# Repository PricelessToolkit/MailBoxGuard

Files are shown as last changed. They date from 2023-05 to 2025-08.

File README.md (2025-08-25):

## ⚠️ MailBox Guard Production is Discontinued. The New version "[PirBOX-LITE](https://github.com/PricelessToolkit/PirBOX-LITE) or [PirBOX-MAX](https://github.com/PricelessToolkit/PirBOX-MAX)"

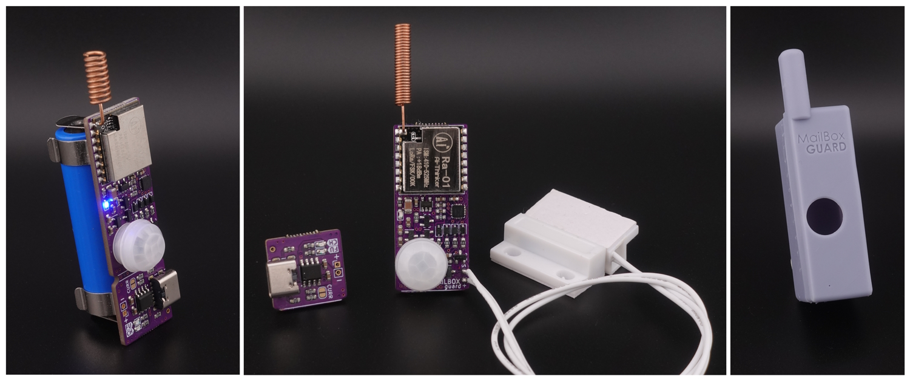
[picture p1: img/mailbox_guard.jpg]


🤗 Please consider subscribing to my [YouTube channel](https://www.youtube.com/@PricelessToolkit/videos)
Your subscription goes a long way in backing my work.



# Long Range "LoRa" Universal MailBox Sensor

### Can be integrated with Home Assistant, used via WhatsApp, or be operated offline.

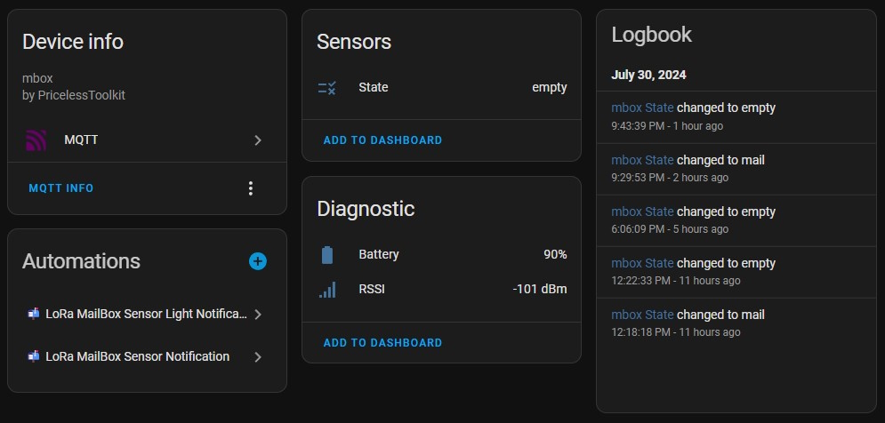
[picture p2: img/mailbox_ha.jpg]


### Use Cases

- Mailbox Sensor - "Code examples are provided"
- Alarm / Motion Sensor

### How it works - Mailbox Use Case

The Mailbox Guard is a device that detects when a new letter or package has been delivered to your mailbox using a PIR sensor and door reed switch. It can send a signal to your LoRa gateway, then the gateway sends a message via WiFi to `Home Assistant "MQTT" or its "API"` or to `WhatsApp` allowing you to receive notifications directly into your phone. Or you can use it offline, the gateway display will show the number of letters received, Battery status, and signal strength.

### Links

- YouTube video https://youtu.be/gf1WWKyEnbg
- My Shop

  - Mailbox Sensor [https://www.pricelesstoolkit.com/](https://www.pricelesstoolkit.com/en/projects/34-41-mailbox-guard-wireless-ir-sensor.html)
  - UNIProg Programmer [https://www.pricelesstoolkit.com/](https://www.pricelesstoolkit.com/en/projects/33-uniprog-uartupdi-programmer-33v.html)
  - Official Multiprotocol Gateway CapiBridge [https://www.pricelesstoolkit.com/](https://www.pricelesstoolkit.com/en/projects/42-129-capibridge-gateway-kit.html#/41-frequency-868_915_mhz)

- Gateway on Aliexpress [LILYGO® TTGO LoRa32 V2.1_1.6 Version 433/868/915Mhz](https://s.click.aliexpress.com/e/_DdCLj19)
- Pogo Pin Clamp [6 Pin Minimum 2.54mm pitch ](https://s.click.aliexpress.com/e/_Dm94yBf)
- Reed Switch "Normally open When the magnet is far away" "For soldering on PCB" https://s.click.aliexpress.com/e/_DkA1Sjp
- Reed Switch with cable "Normally open When the magnet is far away" https://s.click.aliexpress.com/e/_DFNJv1h
- Battery [Li-Ion 14500 800mA](https://s.click.aliexpress.com/e/_DDtU0iT)
- USB Battery charger "just in case" https://s.click.aliexpress.com/e/_DkDAztD

### Sensor Specifications

- Microcontroller "Attiny1616"
- LoRa Bands "433/868/915"
- PIR Sensor AM312 "With the option to turn it off"
- Onboard reed switch "optional"
- External reed switch "Input 2 Pin"
- Battery Holder for "Li-Ion 14500"
- Optional 2 Pin SMD LiPo Battery connector
- Build-in Battery Charger "Can be separated"
  - Connector USB-C
  - Charge status LED "Charging, Full"
- Extremely Low Power Consumption
  - Motion Sensor PIR 11.30uAh
  - Only reed switch 280nAh
  - Every data submission uses 65uA
  - TX LED "With the option to turn it off"
- Size
  - With charger "XXmm to XXmm"
  - Without charger "XXmm to XXmm"
- Programming Protocol
  - UPDI / Serial2UPDI

____________

## 📣 Updates, Bugfixes, and Breaking Changes

> [!NOTE]
>  If you're ready to contribute to the project, your support would be greatly appreciated.

- **22.05.2025** - Breaking Change (XOR obfuscation "Encryption" for LoRa).
- - CapiBridge and MailBox Guard firmware need to be updated.
- **08.05.2025**
  - MailBox Guard Production is Discontinued. The New version "[PirBOX-LITE](https://github.com/PricelessToolkit/PirBOX-LITE) or PirBOX-MAX"
- **30.07.2024**
  - New multisensor Gateway firmware `LoRa_Gateway_MQTT_JSON.ino`
  - Sensor firmware cleanup `Mailbox_Guard_Sensor_MQTT_JSON.ino`

____________

# ⚠️ Battery Polarity ⚠️

- Before connecting the battery, make sure to check the connector polarity on your battery. This is especially important because many 1S LiPo batteries have inverted polarity.

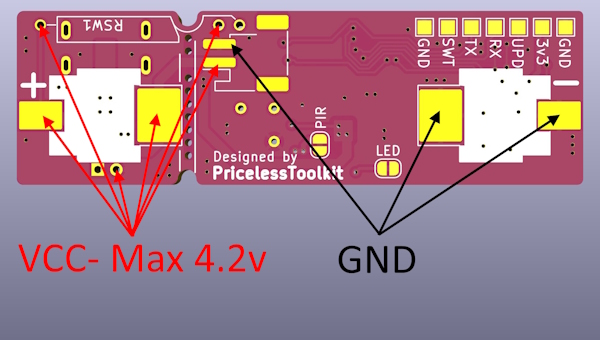
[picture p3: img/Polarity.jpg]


# Arduino IDE Setup

> [!NOTE]
>  For the Library "megaTinyCore" the official recommendation is. Only versions of the Arduino IDE downloaded from https://arduino.cc should be used, NEVER from a Linux package manager. The golden standard is "V1.8.13".

- Additional Boards Manager URLs

  - ESP32 https://raw.githubusercontent.com/espressif/arduino-esp32/gh-pages/package_esp32_dev_index.json
  - megaTinyCore http://drazzy.com/package_drazzy.com_index.json

- Libraries Used
  - LoRa
  - PubSubClient
  - ArduinoJson.h
  - ESP8266 and ESP32 OLED driver for SSD1306 displays
  - UrlEncode
  - HARestAPI "Sketch > Include Library > Add .ZIP Library..."
    - https://github.com/debsahu/HARestAPI
  
-------------

# Choosing a Gateway Hardware
1. [CapiBridge LoRa/ESP-NOW Gateway](https://github.com/PricelessToolkit/CapiBridge): I developed this project, featuring multi-protocol support, including LoRa and ESP-NOW. It will be compatible with my future LoRa and ESP-NOW sensor projects. Purchasing this gateway will support my ongoing open-source developments.
2. LilyGo LoRa Board: This option is more affordable but only supports LoRa. It may not be compatible with all future projects.

# Choosing Firmware for LoRa Gateway

1. **`LoRa_Gateway_MQTT_JSON.ino`** - 🆕 "Home Assistant MQTT Autodiscovery": Automatically discovers and integrates sensors with Home Assistant via MQTT.
   
2. **`LoRa_Gateway_OLED.ino`** - "For Offline Use": Displays new mail notifications, including letter count, signal strength, and battery status. Requires a reset after mail retrieval.

3. **`LoRa_Gateway_WhatsApp.ino`** - Sends a "You have new mail" message to WhatsApp.

4. **`LoRa_Gateway_MQTT.ino`** - Sends raw messages and RSSI to an MQTT server.

5. **`LoRa_Gateway_HARestAPI.ino`** - Sends new mail notifications to Home Assistant via REST API.

# Gateway Configuration

> [!NOTE]
>  If you are using CapiBridge Gateway, configure it using the [Capibridge](https://github.com/PricelessToolkit/CapiBridge) page.

## Select TTGO_LoRa Board Version

- In Arduino IDE select Tools > Board > ESP32 Arduino > `ESP32 Dev Module`
- Change the BOARD definition in `board.h` according to your Lilygo gateway HW Version " 1 = ENABLE / 0 = DISABLE ".

```c
#define LORA_V1_0_OLED  0
#define LORA_V1_2_OLED  0
#define LORA_V1_3_OLED  0
#define LORA_V1_6_OLED  0
#define LORA_V2_0_OLED  1
```

### TTGO Boards GPIOs

| Name | V1.0 | V1.2(T-Fox) | V1.3 | V1.6 | V2.1 |
| --- | ---- | --- | ---- | ---- | ---- |
| OLED RST | 16 | N/A | N/A  | N/A  | N/A  |
| OLED SDA | 4 | 21 | 4 | 21 | 21 |
| OLED SCL | 15 | 22 | 15 | 22 | 22 |
| SDCard CS | N/A  | N/A | N/A  | 13 | 13 |
| SDCard MOSI | N/A  | N/A | N/A  | 15 | 15 |
| SDCard MISO | N/A  | N/A | N/A  | 2 | 2 |
| SDCard SCLK | N/A  | N/A | N/A  | 14 | 14 |
| DS3231 SDA  | N/A  | 21 | N/A  | N/A  | N/A  |
| DS3231 SCL  | N/A  | 22 | N/A  | N/A  | N/A  |
| LORA MOSI | 27 | 27 | 27 | 27 | 27 |
| LORA MISO | 19 | 19 | 19 | 19 | 19 |
| LORA SCLK | 5 | 5 | 5 | 5 | 5 |
| LORA CS | 18 | 18 | 18 | 18 | 18 |
| LORA RST | 14 | 23 | 23 | 23 | 23 |
| LORA DIO0 | 26 | 26 | 26 | 26 | 26 |

## Setting up WIFI and LoRa in the Gateway
- Firmware `LoRa_Gateway_MQTT_JSON.ino`
- Configuration File `config.h`
- The LoRa settings in the gateway and in the sensor must match.

```c
/////////////////////////// Gateway Key ///////////////////////////

#define GATEWAY_KEY "xy" // Keep it short

///////////////////////////////////////////////////////////////////////////////

////////////////////////////// WIFI / MQTT ////////////////////////////////////
#define WIFI_SSID "wifi-name"
#define WIFI_PASSWORD "wifi-password"
#define MQTT_USERNAME "mqtt-username"
#define MQTT_PASSWORD "mqtt-password"
#define MQTT_SERVER "IP-Address"
#define MQTT_PORT 1883

////////////////////////// LoRa Config ////////////////////////////////////////

#define SIGNAL_BANDWITH 125E3  // signal bandwidth in Hz, defaults to 125E3
#define SPREADING_FACTOR 8    // ranges from 6-12, default 7 see API docs
#define CODING_RATE 5          // Supported values are between 5 and 8, corresponding to coding rates of 4/5 and 4/8. The coding rate numerator is fixed at 4.
#define SYNC_WORD 0x12         // byte value to use as the sync word, defaults to 0x12
#define PREAMBLE_LENGTH 6      // Supported values are between 6 and 65535.
#define TX_POWER 20            // TX power in dB, defaults to 17, Supported values are 2 to 20
#define BAND 868E6             // 433E6 / 868E6 / 915E6

///////////////////////////////////////////////////////////////////////////////
```

The remaining is to upload the code into the LilyGo board after that the "LoRaGateway" RSSI entity will appear in the MQTT devices list.

# Mailbox Sensor configuration and Programming

For programming MailBox Guard, you need any 3.3V "UPDI programmer" You can use my other open-source project "UNIProg Programmer" [GitHub](https://github.com/PricelessToolkit/UNIProg_Programmer)

### UPDI Connection Diagram

| UNIProg | MailBox Guard |
| --- | --- |
| GND | GND |
| 3v3 | 3v3 |
| UPD | UPD |

1. In Arduino IDE select the programmer "SerialUPDI-230400 baud"
2. Select board configuration as shown below "screenshot"

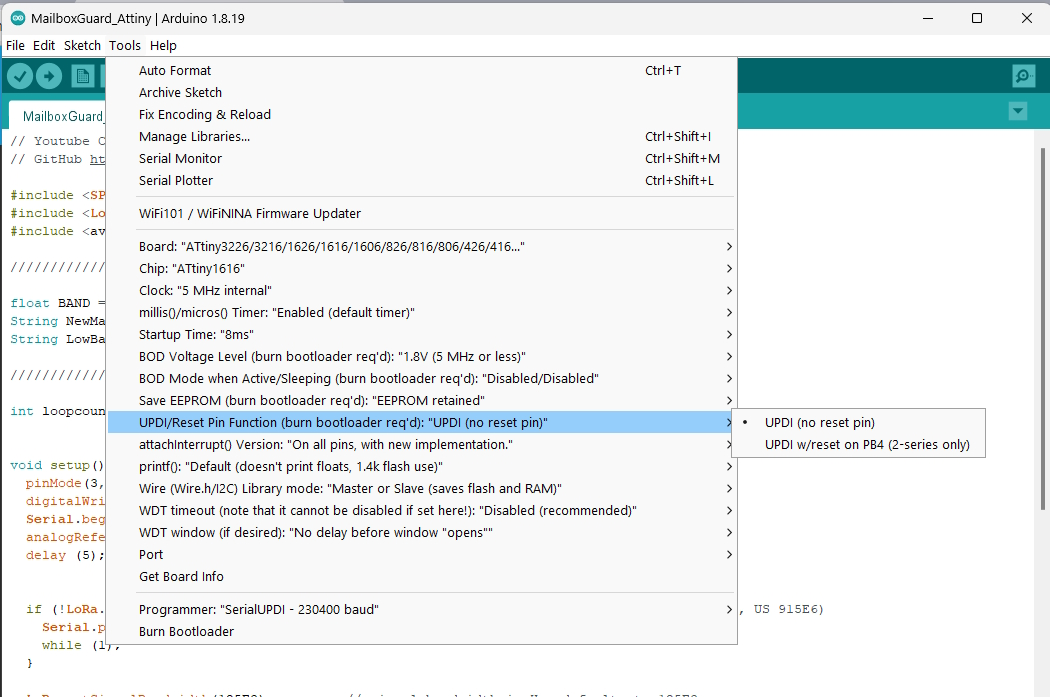
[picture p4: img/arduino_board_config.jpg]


3. Open Sensor firmware `Mailbox_Guard_Sensor_MQTT_JSON.ino` then change  `sensor name`, `gateway key`, and `LoRa` settings according to your needs.

> [!NOTE]
> The LoRa settings must match the gateway ones.

```c

///////////////////////////////// CHANGE THIS /////////////////////////////////

#define SIGNAL_BANDWITH 125E3
#define SPREADING_FACTOR 8
#define CODING_RATE 5
#define SYNC_WORD 0xF3
#define PREAMBLE_LENGTH 6
#define TX_POWER 20
#define BAND 868E6  // 433E6 / 868E6 / 915E6
#define NODE_NAME "mbox" // The name of your sensor must be unique.
#define GATEWAY_KEY "xy" // must match the Gateway key.

///////////////////////////////////////////////////////////////////////////////

```
3. Click "Upload Using Programmer" or "Ctrl + Shift + U"

Done! Once the sensor is triggered for the first time, it will appear in the MQTT devices list on Home Assistant.

# Home Assistant Configuration

## "Automation" Sensor Notification

<details>
<summary>Explanation Click here</summary>

This automation is set up to notify a mobile device when new mail is detected in the mailbox. This setup ensures that whenever new mail is detected by the mailbox sensor, a high-priority notification with relevant details and an image is sent to the specified mobile device. The details of the automation are as follows:

#### Trigger
- **Platform:** State
- **Entity:** `sensor.mbox_state`
- **To State:** `mail`
- **For Duration:** 1 second
- **From State:** Not specified (null)

This means that the automation will trigger when the state of `sensor.mbox_state` changes to `mail` and remains in that state for at least 1 second. The "From State" being null indicates that the trigger does not depend on the previous state of the sensor.

#### Condition
There are no conditions specified, so this automation will run whenever the trigger criteria are met.

#### Action
- **Service:** `notify.mobile_app_doogee_v20pro`
- **Data:**
  - **Message:** "Mailbox is Full!"
  - **Title:** "New Mail!"
  - **Additional Data:**
    - **URL:** `/lovelace/home` - A link to the Home Assistant dashboard.
    - **Persistent:** `true` - Ensures the notification stays on the device until manually dismissed.
    - **Importance:** `high` - Sets the priority of the notification.
    - **Channel:** `MailBox` - Specifies the notification channel, useful for Android devices.
    - **Tag:** `mailbox` - A tag to help categorize the notification.
    - **Image:** `/media/local/notify/mailbox.jpg` - An image included in the notification.
    - **Actions:**
      - **Action:** `received` - A custom action identifier.
      - **Title:** "I took the parcel" - A label for the action button in the notification.

#### Mode
- **Mode:** `single` - Ensures that only one instance of this automation can run at a time.

</details>

```yaml

alias: 📬 LoRa MailBox Sensor Notification
description: ""
trigger:
  - platform: state
    entity_id:
      - sensor.mbox_state
    to: mail
    for:
      hours: 0
      minutes: 0
      seconds: 1
    from: null
condition: []
action:
  - service: notify.mobile_app_doogee_v20pro
    data:
      message: Mailbox is Full !
      title: New Mail!
      data:
        url: /lovelace/home
        persistent: true
        importance: high
        channel: MailBox
        tag: mailbox
        image: /media/local/notify/mailbox.jpg
        actions:
          - action: received
            title: I took the parcel
mode: single

```

## "Automation"  MailBox Dismiss Notification from Notification

<details>
<summary>Explanation Click here</summary>

This automation is designed to handle the dismissal of a notification when a specific action is triggered on a mobile device. Works by sending an MQTT message to update the state of the mailbox sensor and then clearing the corresponding notifications on specified mobile devices. The details of the automation are as follows:

#### Trigger
- **Platform:** Event
- **Event Type:** `mobile_app_notification_action`
- **Event Data:**
  - **Action:** `received`

This means the automation is triggered when the mobile app receives a notification action event with the action identifier `received`.

#### Condition
There are no conditions specified, so this automation will run whenever the trigger criteria are met.

#### Action
1. **Service:** `mqtt.publish`
   - **Data:**
     - **QoS:** `0` - Quality of Service level.
     - **Retain:** `true` - Retains the message on the MQTT broker.
     - **Topic:** `homeassistant/sensor/YourSensorName/state` - The MQTT topic to publish to.
     - **Payload:** `empty` - The message content, indicating the mailbox state is now empty.

2. **Service:** `notify.mobile_app_doogee_v20pro`
   - **Data:**
     - **Message:** `clear_notification` - Clears the notification.
     - **Data:**
       - **Tag:** `mailbox` - Identifies which notification to clear.

3. **Service:** `notify.mobile_app_oneplus8t`
   - **Data:**
     - **Message:** `clear_notification` - Clears the notification.
     - **Data:**
       - **Tag:** `mailbox` - Identifies which notification to clear.

#### Mode
- **Mode:** `single` - Ensures that only one instance of this automation can run at a time.

</details>

```yaml

alias: 📬 LoRa MailBox Dismiss Notification
description: ""
trigger:
  - platform: event
    event_data:
      action: received
    event_type: mobile_app_notification_action
condition: []
action:
  - service: mqtt.publish
    data:
      qos: 0
      retain: true
      topic: homeassistant/sensor/YourSensorName/state
      payload: empty
  - service: notify.mobile_app_doogee_v20pro
    data:
      message: clear_notification
      data:
        tag: mailbox
  - service: notify.mobile_app_oneplus8t
    data:
      message: clear_notification
      data:
        tag: mailbox
mode: single

```

## "Script" MailBox Status Reset for using from Dashboard

```yaml
alias: MailBox Status Reset and Dismiss Notification
sequence:
  - service: mqtt.publish
    data:
      qos: "0"
      retain: true
      topic: homeassistant/sensor/YourSensorName/state
      payload: empty
  - service: notify.mobile_app_doogee_v20pro
    data:
      data:
        tag: mailbox
      message: clear_notification
  - service: notify.mobile_app_oneplus8t
    data:
      message: clear_notification
      data:
        tag: mailbox
mode: single

```

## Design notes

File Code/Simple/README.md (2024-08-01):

# This readme is for Sample, OLED and WhatsApp Frimware

## Gateway code

1. **`LoRa_Gateway_OLED.ino`** - "For Offline Use": Displays new mail notifications, including letter count, signal strength, and battery status. Requires a reset after mail retrieval.

2. **`LoRa_Gateway_WhatsApp.ino`** - Sends a "You have new mail" message to WhatsApp.

3. **`LoRa_Gateway_MQTT.ino`** - Sends raw messages and RSSI to an MQTT server.

To pair these gateways with a sensor, use the sensor code `Mailbox_Guard_Sensor_Simple.ino`

## Arduino IDE Setup

> [!NOTE]
>  For the Library "megaTinyCore" the official recommendation is. Only versions of the Arduino IDE downloaded from https://arduino.cc should be used, NEVER from a Linux package manager. The golden standard is "V1.8.13".

- Additional Boards Manager URLs

  - ESP32 https://raw.githubusercontent.com/espressif/arduino-esp32/gh-pages/package_esp32_dev_index.json
  - megaTinyCore http://drazzy.com/package_drazzy.com_index.json

- Libraries Used
  - LoRa
  - ESP8266 and ESP32 OLED driver for SSD1306 displays
  - HTTPClient
  - UrlEncode
  
## Gateway Configuration

> [!NOTE]
>  If you are using CapiBridge Gateway, configure it using the [Capibridge](https://github.com/PricelessToolkit/CapiBridge) page.

## Select TTGO_LoRa Board Version

- In Arduino IDE select Tools > Board > ESP32 Arduino > `ESP32 Dev Module`
- Change the BOARD definition in `board.h` according to your Lilygo gateway HW Version " 1 = ENABLE / 0 = DISABLE ".

```c
#define LORA_V1_0_OLED  0
#define LORA_V1_2_OLED  0
#define LORA_V1_3_OLED  0
#define LORA_V1_6_OLED  0
#define LORA_V2_0_OLED  1
```

### TTGO Boards GPIOs

| Name | V1.0 | V1.2(T-Fox) | V1.3 | V1.6 | V2.1 |
| --- | ---- | --- | ---- | ---- | ---- |
| OLED RST | 16 | N/A | N/A  | N/A  | N/A  |
| OLED SDA | 4 | 21 | 4 | 21 | 21 |
| OLED SCL | 15 | 22 | 15 | 22 | 22 |
| SDCard CS | N/A  | N/A | N/A  | 13 | 13 |
| SDCard MOSI | N/A  | N/A | N/A  | 15 | 15 |
| SDCard MISO | N/A  | N/A | N/A  | 2 | 2 |
| SDCard SCLK | N/A  | N/A | N/A  | 14 | 14 |
| DS3231 SDA  | N/A  | 21 | N/A  | N/A  | N/A  |
| DS3231 SCL  | N/A  | 22 | N/A  | N/A  | N/A  |
| LORA MOSI | 27 | 27 | 27 | 27 | 27 |
| LORA MISO | 19 | 19 | 19 | 19 | 19 |
| LORA SCLK | 5 | 5 | 5 | 5 | 5 |
| LORA CS | 18 | 18 | 18 | 18 | 18 |
| LORA RST | 14 | 23 | 23 | 23 | 23 |
| LORA DIO0 | 26 | 26 | 26 | 26 | 26 |

## Mailbox Sensor configuration and Programming

For programming MailBox Guard, you need any 3.3V "UPDI programmer" You can use my other open-source project "UNIProg Programmer" [GitHub](https://github.com/PricelessToolkit/UNIProg_Programmer)

### UPDI Connection Diagram

| UNIProg | MailBox Guard |
| --- | --- |
| GND | GND |
| 3v3 | 3v3 |
| UPD | UPD |

1. In Arduino IDE select the programmer "SerialUPDI-230400 baud"
2. Select board configuration as shown below "screenshot"



3. Open Sensor firmware `Mailbox_Guard_Sensor_Simple` then change  `NewMailCode`, `LowBatteryCode`, and `LoRa` settings according to your needs.

> [!NOTE]
> The LoRa settings must match the gateway ones.

```c
//////////////////////////////////// CONFIG /////////////////////////////////////////////

#define SignalBandwidth 125E3
#define SpreadingFactor 12
#define CodingRate 8
#define SyncWord 0xF3
#define PreambleLength 8
#define TxPower 20
#define BAND 868E6     // frequency in Hz (ASIA 433E6, EU 868E6, US 915E6)
String NewMailCode = "REPLACE_WITH_NEW_MAIL_CODE"; // For Example "0xA2B2";
String LowBatteryCode = "REPLACE_WITH_LOW_BATTERY_CODE"; // For Example "0xLBAT";

/////////////////////////////////////////////////////////////////////////////////////////

4. Click "Upload Using Programmer" or "Ctrl + Shift + U"

```

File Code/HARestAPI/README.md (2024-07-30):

## HARestAPI Configuration

- Open `LoRa_Gateway_HARestAPI.ino`
- For the `ha_pwd` go to your User Profile > Long-Lived Access Tokens > Create Token

```c
const char* ha_ip = "192.168.0.xxx";
uint16_t ha_port = 8123;
const char* ha_pwd = "HA_PASSWORD";
```

## HARestAPI

- File `configuration.yaml`

```yaml
input_boolean:
  mailbox_guard_motion:
    name: Mailbox Guard Motion
    icon: mdi:mail
  mailbox_guard_low_battery:
    name: Mailbox Guard Low Battery
    icon: mdi:battery

input_number:
  mailbox_guard_count:
    name: Mailbox Guard Count
    min: 0
    max: 255
    icon: mdi:mail
  mailbox_guard_battery:
    name: Mailbox Guard Battery
    min: 0
    max: 100
    icon: mdi:battery
  mailbox_guard_rssi:
    name: Mailbox Guard RSSI
    min: -196
    max: 63
    icon: mdi:signal
  mailbox_guard_snr:
    name: Mailbox Guard SNR
    min: -32.0
    max: 32.0
    icon: mdi:waves
```

- File `automation.yaml`

```yaml
- id: "1693702614043"
  alias: Mailbox Guard Motion
  description: ""
  trigger:
    - platform: state
      entity_id: input_boolean.mailbox_guard_motion
      to: "on"
  condition: []
  action:
    - service: notify.notify
      data:
        message: You've Got Mail!
    - service: input_number.set_value
      data:
        entity_id: input_number.mailbox_guard_count
        value: "{{ (states.input_number.mailbox_guard_count.state | int) + 1 }}"
    - service: input_boolean.turn_off
      data:
        entity_id: input_boolean.mailbox_guard_motion
  mode: single
- id: "1693703621871"
  alias: Mailbox Guard Low Battery
  description: ""
  trigger:
    - platform: state
      entity_id: input_boolean.mailbox_guard_low_battery
      to: "on"
  condition: []
  action:
    - service: notify.notify
      data:
        message: Mailbox Guard Low Battery!
    - service: input_boolean.turn_off
      data:
        entity_id: input_boolean.mailbox_guard_low_battery
  mode: single
```

- Dashboard card

```yaml
type: entities
title: Mailbox Guard
show_header_toggle: false
entities:
  - type: conditional
    conditions: []
    row:
      type: sensor-entity
      entity: input_number.mailbox_guard_count
      name: Motion Count
  - type: button
    icon: mdi:sync
    name: Reset Count
    action_name: RESET
    tap_action:
      action: call-service
      service: input_number.set_value
      data:
        entity_id: input_number.mailbox_guard_count
        value: 0
  - type: conditional
    conditions: []
    row:
      type: sensor-entity
      entity: input_number.mailbox_guard_battery
      name: Battery
  - type: conditional
    conditions: []
    row:
      type: sensor-entity
      entity: input_number.mailbox_guard_rssi
      name: RSSI
  - type: conditional
    conditions: []
    row:
      type: sensor-entity
      entity: input_number.mailbox_guard_snr
      name: SNR
```

### MailBox Guard motion detection events

1. Your phone receives a notification from HA `You've Got Mail!`
2. The MailBox Guard will add a count to the `Motion Count`
3. When you fetch the mail select the `RESET` button



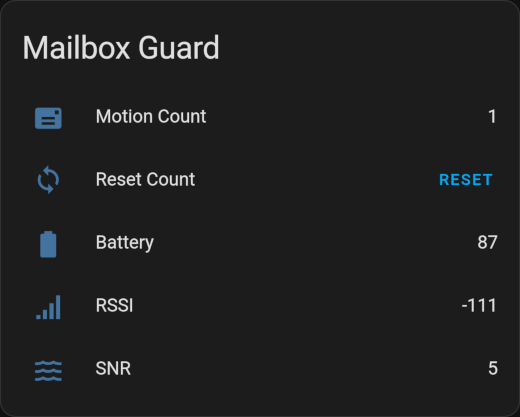
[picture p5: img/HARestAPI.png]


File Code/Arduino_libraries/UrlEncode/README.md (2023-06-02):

# UrlEncode

A simple library for URL encoding on Arduino framework.

## Usage

```cpp
#include <UrlEncode.h>

String encoded = urlEncode("http://example.com/path/to/file.html?param=value&param2=value2");
```

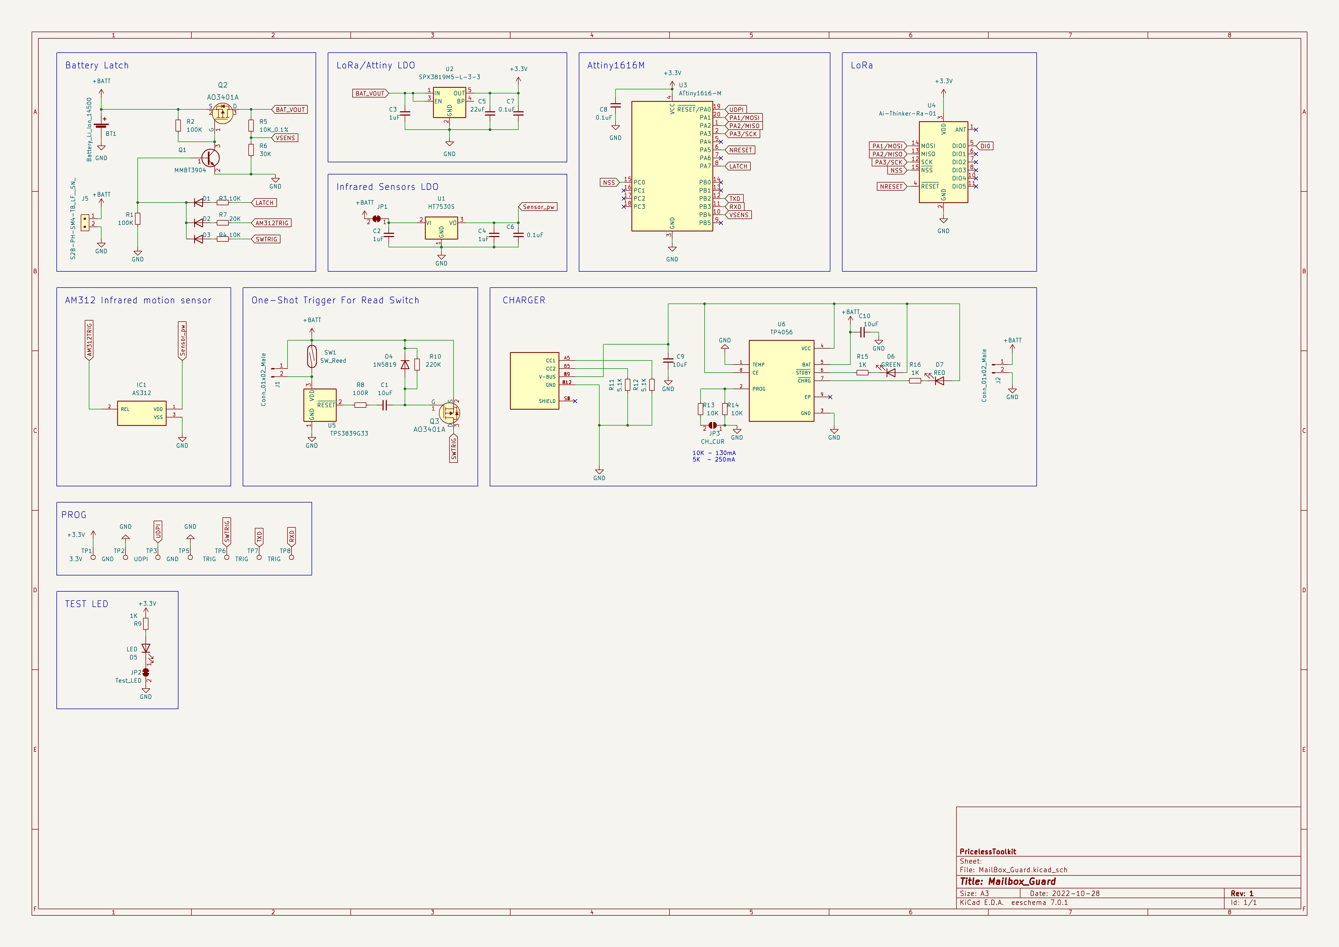
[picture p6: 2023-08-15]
PCB/MailBox_Guard_Schematic.jpg

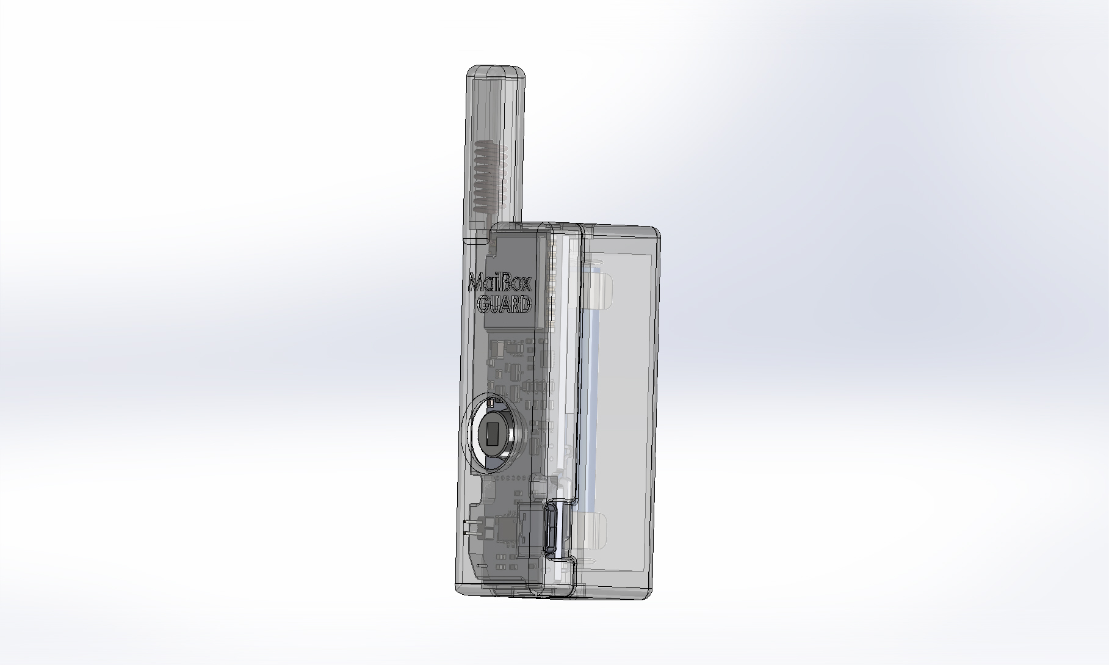
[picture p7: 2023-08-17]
img/3D_case1.JPG

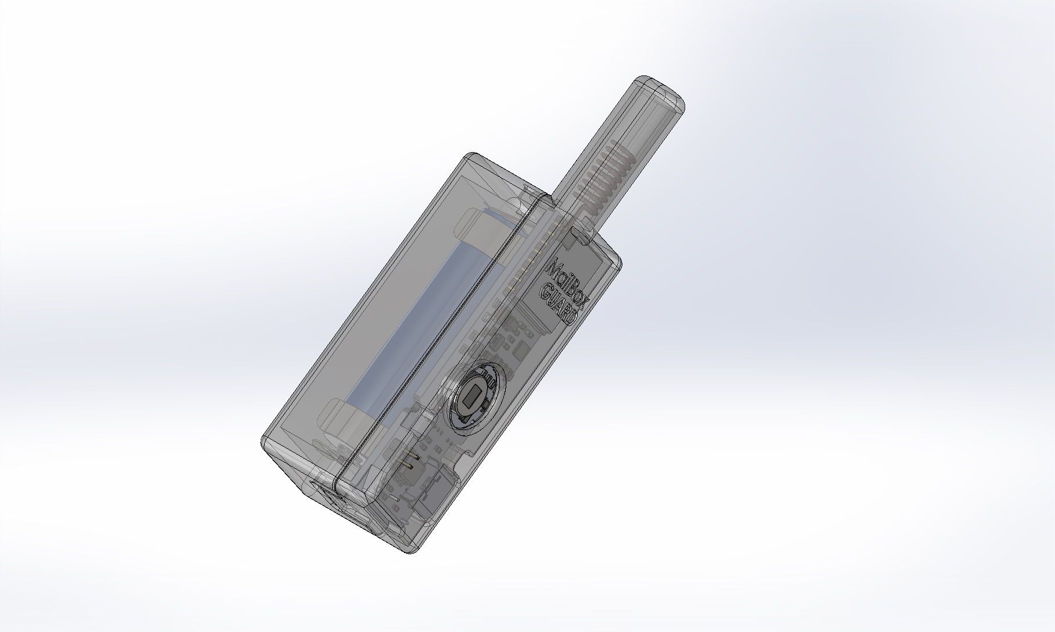
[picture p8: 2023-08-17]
img/3D_case2.JPG

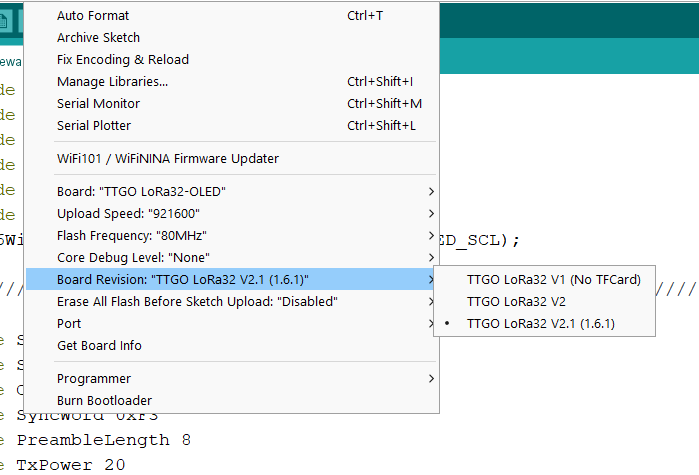
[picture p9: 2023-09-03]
img/TTGo_V2_1___1_6_1.png

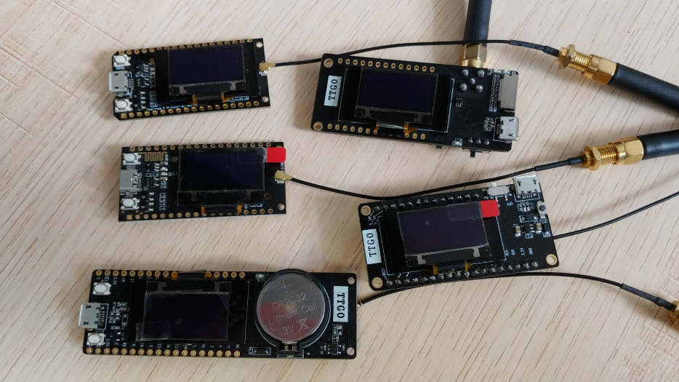
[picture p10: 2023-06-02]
img/ttgo.png

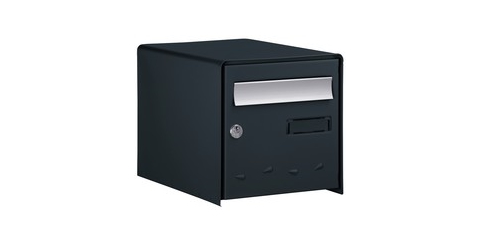
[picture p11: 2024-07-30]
img/mailbox.jpg

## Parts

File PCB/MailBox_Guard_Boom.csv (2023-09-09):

Id | Designator | Footprint | Quantity | Designation | Mfr. Part | Supplier: LCSC | Supplier: Other
1 | C3,C2,C4 | C_0603_1608Metric | 3 | 1uF
2 | C10,C9,C1 | C_0603_1608Metric | 3 | 10uF
3 | J3 | CUI_UJC-HP-3-SMT-TR | 1 | UJC-HP-3-SMT-TR | U262-061N-4BVC11 | C2764612
4 | Q3,Q2 | SOT-23-3 | 2 | AO3401A | AO3401A | C15127
5 | D4,D3,D1,D2 | D_SOD-323 | 4 | 1N5819 |  | C489147
6 | U6 | ESOP-8-EP | 1 | TP4056 | TP4056 | C5311018
7 | Q1 | SOT-23 | 1 | MMBT3904 |  | C20526
8 | R2,R1 | R_0603_1608Metric | 2 | 100K
9 | C5 | C_1206_3216Metric | 1 | 22uF |  | C12891
10 | R7 | R_0603_1608Metric | 1 | 20K
12 | C6,C7,C8 | C_0603_1608Metric | 3 | 0.1uF
13 | R12,R11 | R_0603_1608Metric | 2 | 5.1K
14 | U3 | VQFN-20 | 1 | ATtiny1616 | ATTINY1616-MFR | C1338523
15 | R5 | R_0603_1608Metric | 1 | 10K_0.1% |  | C309083
16 | R16,R15,R9 | R_0603_1608Metric | 3 | 1K
17 | R10 | R_0603_1608Metric | 1 | 220K
18 | U1 | HT7530S | 1 | HT7530S | HT7530S | C347214
20 | U5 | SOT-23-3 | 1 | TPS3839G33DBZR | TPS3839G33DBZR | TPS3839G33DBZR
21 | IC1 | AS312-NEW | 1 | AS312 | AS312 | C90465
22 | R8 | R_0603_1608Metric | 1 | 100R
23 | R3,R14,R4,R13 | R_0603_1608Metric | 4 | 10K
24 | R6 | R_0603_1608Metric | 1 | 30K_0.1% |  | C319658
25 | D5 | LED_0603_1608Metric | 1 | BLUE
27 | U4 | Ai-Thinker-Ra-01 | 1 | Ai-Thinker-Ra-01 433Mhz or Ra-01H 868/915Mhz | Ra-01 or Ra-01H | C503593 / C90040
28 | D6 | LED_0603_1608Metric | 1 | GREEN
29 | D7 | LED_0603_1608Metric | 1 | RED
30 | U2 | SOT-23-5 | 1 | SPX3819M5-L-3-3 | SPX3819M5-L-3-3/TR | C9055
37 | BT1 |  | 1 | Battery_Li_Ion_14500
39 | J5 | JST_PH_S2B-PH-SM4-TB_1x02-1MP_P2.00mm_Horizontal | 1 | S2B-PH-SM4-TB_LF__SN_ "Li-Po Battery Connector" | S2B-PH-SM4-TB(LF)(SN)
40 |  |  | 1 | Fresnel lens for AS312 |  |  | Aliexpress
41 |  |  | 1 | 433/868/915Mhz Spring Antenna90d |  |  | Aliexpress
42 |  |  | 1 | MYOUNG MY-AA-04 AA Battery Holder | MY-AA-04 | C2979179
 |  |  |  | Select capacitors and resistors with a voltage of 10V and above

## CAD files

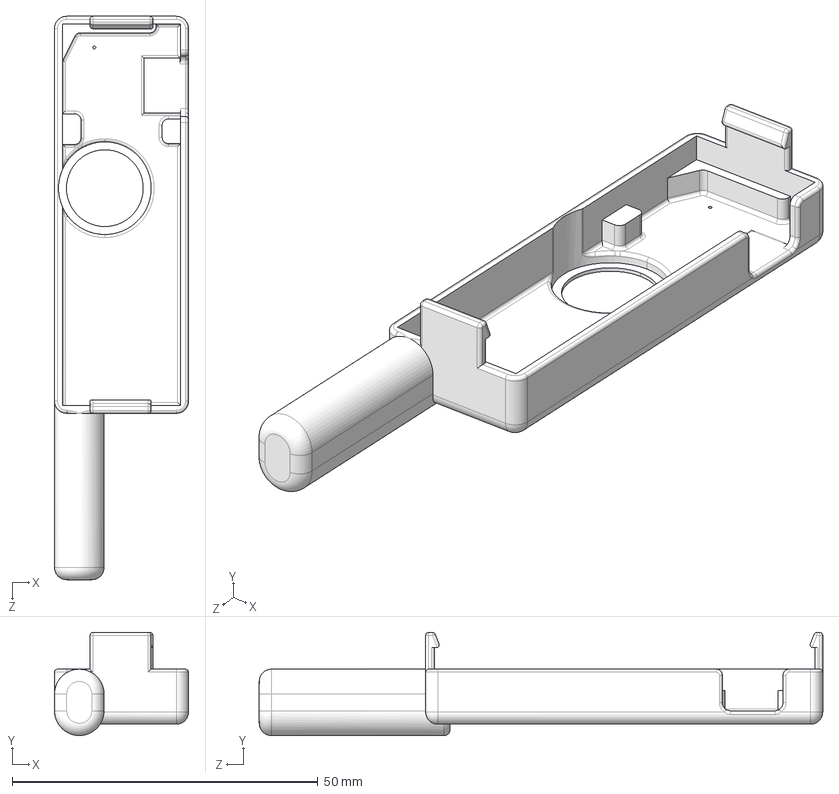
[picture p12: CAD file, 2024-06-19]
3D/Step/MailBoxGuard_Full_Size_Front_868_915.STEP
21.9 x 16.8 x 92.1 mm

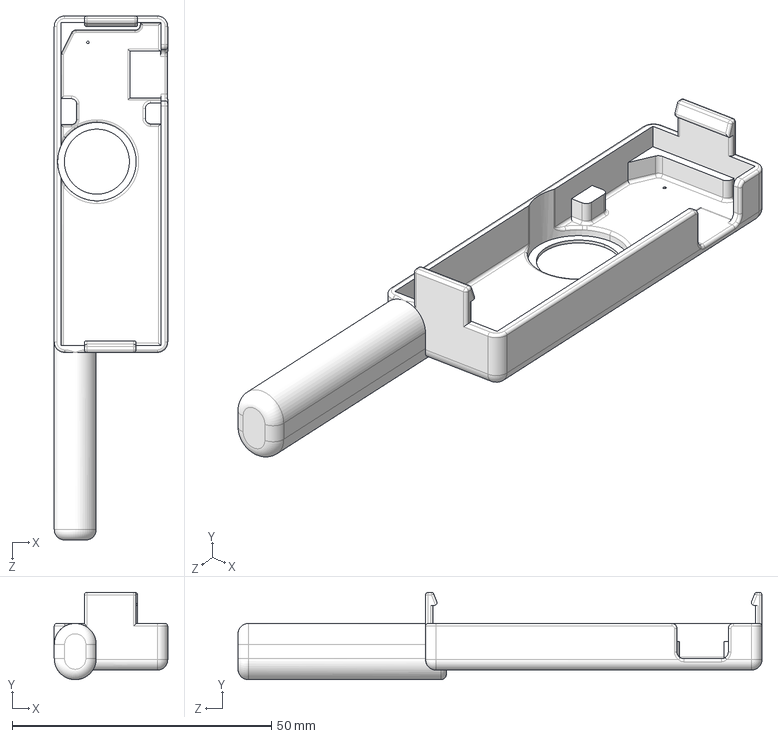
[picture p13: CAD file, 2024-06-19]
3D/Step/MailBoxGuard_Full_Size_Front_433.STEP
21.9 x 16.8 x 101.1 mm

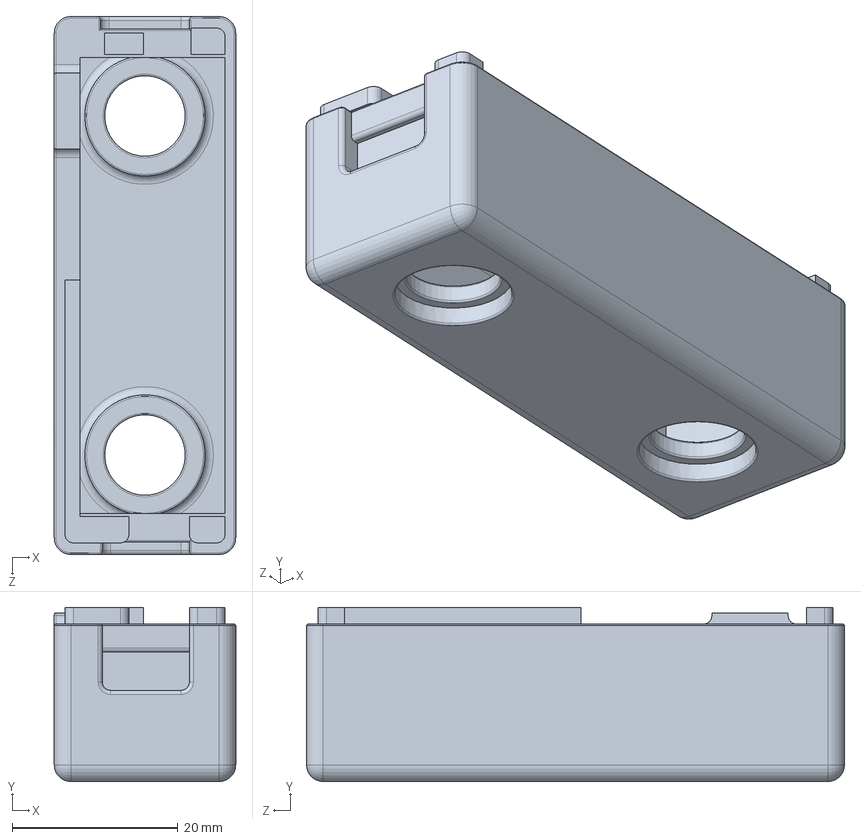
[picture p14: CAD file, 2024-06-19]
3D/Step/MailBoxGuard_Full_Size_Back_433_868_915_Magnetic_Open_12x2mm.SLDPRT
21.9 x 21.0 x 64.9 mm

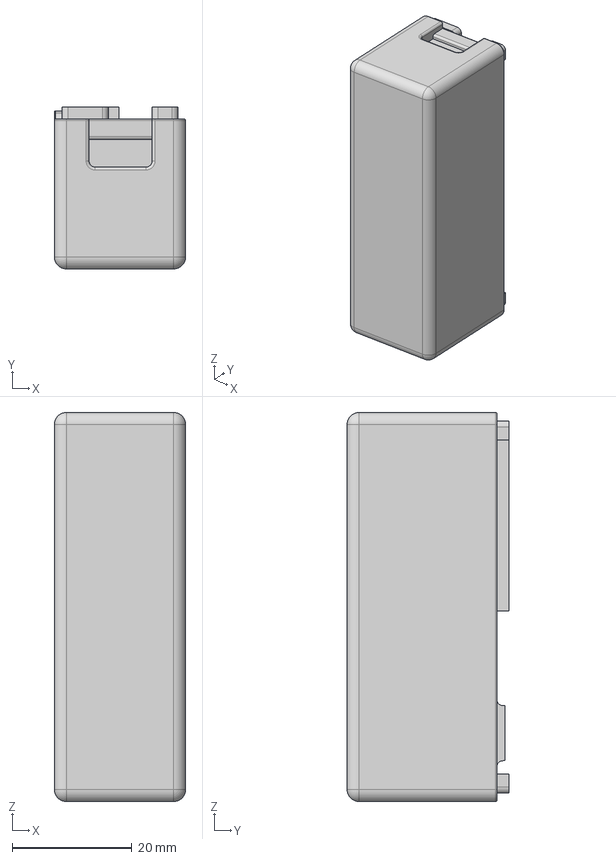
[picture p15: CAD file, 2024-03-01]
3D/Step/MailBoxGuard_Full_Size_Back_433_868_915.Magnet.step
21.9 x 27.0 x 64.9 mm

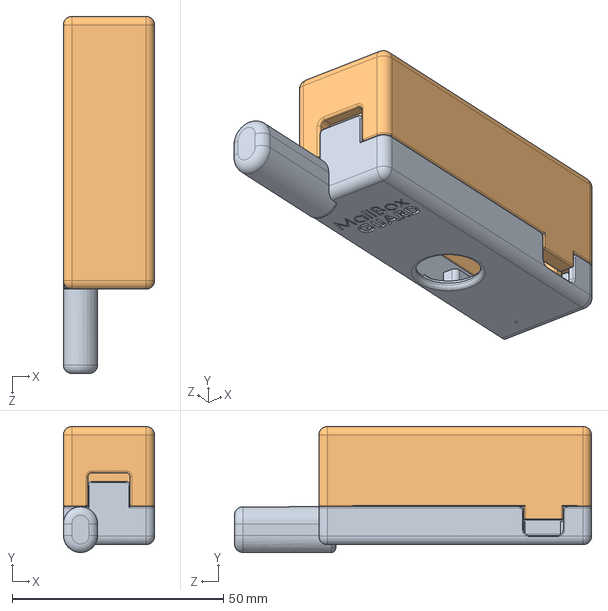
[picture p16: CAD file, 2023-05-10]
3D/Step/Assem1.SLDASM
21.6 x 29.9 x 84.6 mm
MailBoxGuard_Full_Size_Front_868_915
MailBoxGuard_Full_Size_Back_868_915

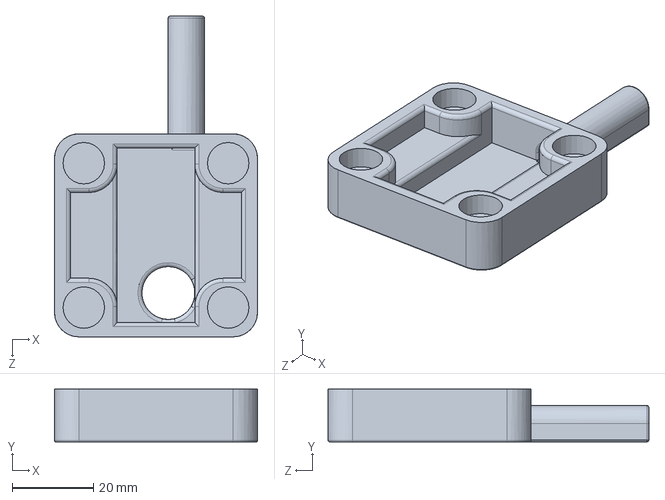
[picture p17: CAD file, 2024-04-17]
3D/Step/MailBoxGuard_Half_Size_Magnetic.SLDPRT
50.0 x 13.0 x 79.0 mm

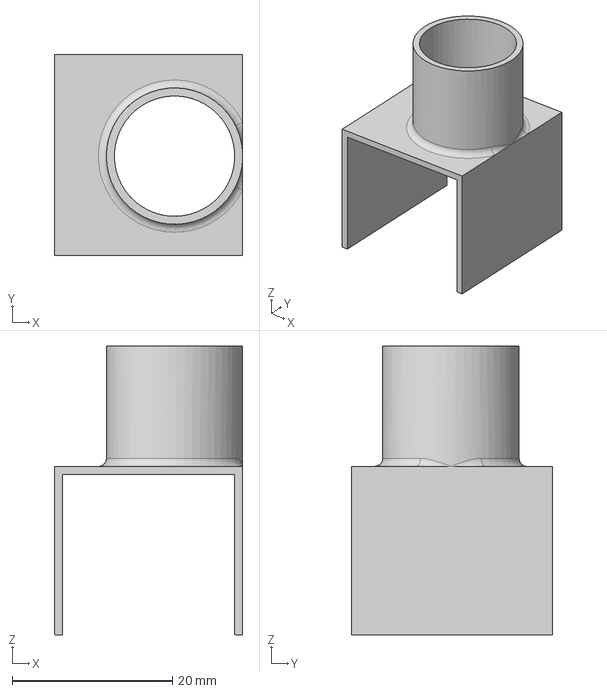
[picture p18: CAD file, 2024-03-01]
3D/Step/Restriktor.step
23.5 x 25.0 x 36.0 mm

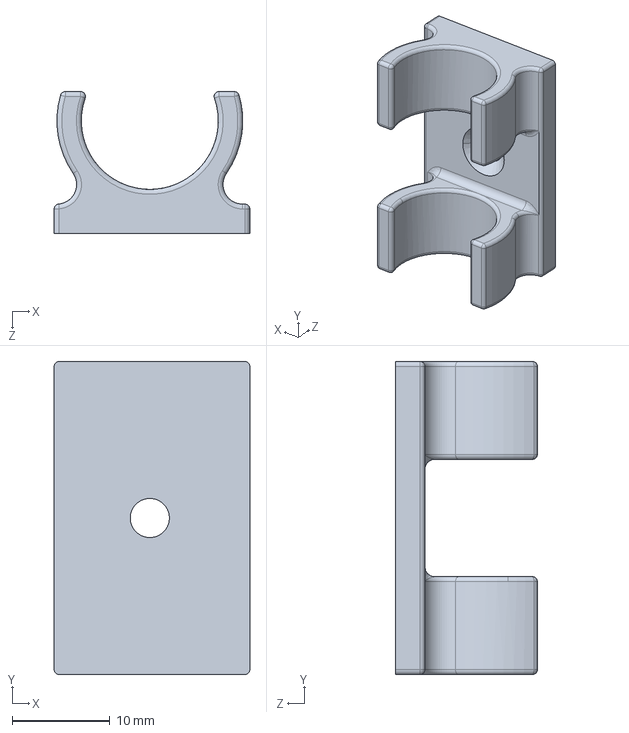
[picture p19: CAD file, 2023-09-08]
3D/Step/Wall_Support_BT14500.STEP
20.0 x 32.0 x 14.5 mm

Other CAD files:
3D/Step/MailBoxGuard_Full_Size_Back_433_868_915.STEP
3D/Step/MailBoxGuard_Full_Size_Front_433_868_915.SLDPRT
3D/STL/MailBoxGuard_Full_Size_Back_433_868_915.Magnet.stl
3D/STL/MailBoxGuard_Full_Size_Back_433_868_915.STL
3D/STL/MailBoxGuard_Full_Size_Back_433_868_915_Magnetic_Open_12x2mm.STL
3D/STL/MailBoxGuard_Full_Size_Front_433.STL
3D/STL/MailBoxGuard_Full_Size_Front_433_868_915.STL
3D/STL/MailBoxGuard_Full_Size_Front_868_915.STL
3D/STL/MailBoxGuard_Half_Size_Magnetic.STL
3D/STL/Restriktor.stl
3D/STL/Wall_Support_BT14500.STL
3D/Step/MailBoxGuard_Full_Size_Back_433_868_915.SLDPRT
3D/Step/MailBoxGuard_Full_Size_Front_433.SLDPRT
3D/Step/MailBoxGuard_Full_Size_Front_868_915.SLDPRT
3D/Step/Wall_Support_BT14500.SLDPRT

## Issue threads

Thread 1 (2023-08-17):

Request: 3D case

WhistleMaster, 2023-08-17:
Hi !

Thanks for the great work ! I've ordered the PCB on your shop and I'm looking for the 3D case.

Thanks !
Regards,

WM

PricelessToolkit, 2023-08-17:
Thanks for your support! 🤗  there are the STEP files, I forgot to export them to STL. Today I will upload them too.

PricelessToolkit, 2023-08-17:
Done!

Closed 2023-08-18.

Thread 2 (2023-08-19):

Boom file

danielducu, 2023-08-19:
I think boom file is incorrect / incomplete.

PricelessToolkit, 2023-08-19:
Why?

danielducu, 2023-08-20:
> Why?

More of a request then an issue hehe, the "Supplier and ref" is missing.

PricelessToolkit, 2023-08-21:
You can buy components wherever you want Digikey.com, lcsc.com.... right now it's hard to find components in one place.

PricelessToolkit, 2023-08-21:
Added manufacturer's part numbers for important parts only. for resistors and LEDs there are sizes and values.

CommittotheIndian, 2023-12-15:
I've attempted to upload this to PCBway and have them assemble. It would appear they are having issues with your formatting. The assembly step has been in audit for hours with no response from PCBway.

Any suggestions?

PricelessToolkit, 2023-12-15:
I think they need to check components' stock disponibility..... so wait until the audit ends "It can take 24+ hours"

CommittotheIndian, 2023-12-16:
They are having issues with designators and part numbers on the last 3 items.

They also asked about the battery but I can purchase separate.

<html xmlns:v="urn:schemas-microsoft-com:vml"
xmlns:o="urn:schemas-microsoft-com:office:office"
xmlns:x="urn:schemas-microsoft-com:office:excel"
xmlns="http://www.w3.org/TR/REC-html40">

<head>

<meta name=ProgId content=Excel.Sheet>
<meta name=Generator content="Microsoft Excel 15">
<link id=Main-File rel=Main-File
href="file:////Users/PunkButt/Library/Group%20Containers/UBF8T346G9.Office/TemporaryItems/msohtmlclip/clip.htm">
<link rel=File-List
href="file:////Users/PunkButt/Library/Group%20Containers/UBF8T346G9.Office/TemporaryItems/msohtmlclip/clip_filelist.xml">
<style>
<!--table
	{mso-displayed-decimal-separator:"\.";
	mso-displayed-thousand-separator:"\,";}
@page
	{margin:1.0in .75in 1.0in .75in;
	mso-header-margin:.51in;
	mso-footer-margin:.51in;}
tr
	{mso-height-source:auto;}
col
	{mso-width-source:auto;}
br
	{mso-data-placement:same-cell;}
td
	{padding-top:1px;
	padding-right:1px;
	padding-left:1px;
	mso-ignore:padding;
	color:windowtext;
	font-size:12.0pt;
	font-weight:400;
	font-style:normal;
	text-decoration:none;
	font-family:宋体;
	mso-generic-font-family:auto;
	mso-font-charset:134;
	mso-number-format:General;
	text-align:general;
	vertical-align:middle;
	border:none;
	mso-background-source:auto;
	mso-pattern:auto;
	mso-protection:locked visible;
	white-space:nowrap;
	mso-rotate:0;}
.xl65
	{font-family:Arial;
	mso-generic-font-family:auto;
	mso-font-charset:0;}
.xl66
	{font-size:10.0pt;
	font-family:Arial;
	mso-generic-font-family:auto;
	mso-font-charset:0;
	text-align:left;
	border:.5pt solid black;}
-->
</style>
</head>

<body link=blue vlink=purple>

30 |   | 1 |   | Fresnel lens   for AS312 | Aliexpress
-- | -- | -- | -- | -- | --
31 |   | 1 |   | 433/868/915Mhz Spring   Antenna90d | Aliexpress
32 |   | 1 | MY-AA-04 | MYOUNG MY-AA-04 AA   Battery Holder | C2979179

</body>

</html>

[T-B2W582299A-5sets-MailBox_Guard_Boom(2023-12-16).xls](https://github.com/PricelessToolkit/MailBoxGuard/files/13693013/T-B2W582299A-5sets-MailBox_Guard_Boom.2023-12-16.xls)

PricelessToolkit, 2023-12-16:
30,31 You need to buy from Ali and hand solder, 32 from LCSC need to be hand-soldered on the back side of the PCB.   PS: how much do they want for full assembly + shipping? is the difference very big? compared to my store?

CommittotheIndian, 2023-12-16:
I know those need to be hand soldered but hoping if I just added that note, they could just throw them in the box (save me on cost since I don't need batches of 10+).

I started this with 5 units but I only need 1. They are the same cost 1 vs 5 accept when it comes to the individual parts. So If I take it back down to 1 assembled and shipped, I think I'm looking at $48-$50 US. Right now I'm just getting quotes.

I'd much rather just purchase from you since it is your design and I like helping the little guy but with yours + shipping + and EU conversion, it's $70 just for one unit without anything else. I was going to spend over $100 for a mailbox sensor.

PricelessToolkit, 2023-12-16:
868Mhz version tested + shipping is 65.45 USD / 433 is 61 USD. For me no difference whether you pay for an assembly service or buy a directly from my shop. The main thing for me is that you liked the project! if you have any questions about the setup, open a discussion, good luck 👍

Closed 2023-12-28.

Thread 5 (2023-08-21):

KiCad files

dtown123, 2023-08-21:
Hello - thanks for your great work on this project!  I'm learning a lot from it.

1.  Any chance you could include the KiCad project files in this?  I was trying to follow along with the provided schematic and it's much easier to do in KiCad's IDE.
2. Looking at the RA-01 module on the schematic, does DI00 actually connect to anything?

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

Thanks again!

PricelessToolkit, 2023-08-21:
Hi, Thank you, I'm glad this project is useful for you.

1. I'm sorry, but no, I don't want the mailbox sensor to appear on Aliexpress after 30 minutes "This has already happened once"
2. Not connected

If you have any other questions feel free to ask

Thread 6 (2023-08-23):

Request: OTAA

WhistleMaster, 2023-08-23:
Hi !

Thanks again the great work on those projects!

I was wondering if that would be possible to have a version of the sensor code which would use OTAA to join other Lora networks such as TTN ?

Thanks !
Kind regards,

WM

PricelessToolkit, 2023-08-23:
Hi!

I think there is only one gateway in my area and it is far away, so I have never tried using TTN. But if I find free time, I'll try. Do you have experience with Arduino coding?

WhistleMaster, 2023-08-23:
Thanks ! I have a bit of experience with Arduino coding. I've found some example such as [MailboxNotifier](https://github.com/SensorsIot/MailboxNotifier/blob/main/MailboxNotifier1284P_V3/MailboxNotifier1284P_V3.ino), similar to the MaiBoxGuard sensor, but using OTAA to join LoraWan networks or also [LilyGo](https://github.com/Xinyuan-LilyGO/LilyGo-LoRa-Series/blob/master/examples/LoRaWAN/OTTA/OTTA.ino).

WhistleMaster, 2023-08-23:
Based on those examples, I've tried something: [ttn_otaa.ino.zip](https://github.com/PricelessToolkit/MailBoxGuard/files/12421591/ttn_otaa.ino.zip) but the issue I have is, I guess, the limited size of the micro controller Attiny1616 because I get an error at compilation which is:

```
region `text' overflowed by 9345 bytes
```

PricelessToolkit, 2023-08-23:
can you attach libraries too?

WhistleMaster, 2023-08-24:
Sure ! The only additional one needed is `MCCI_LoRaWAN_LMIC_library` [libraries.zip](https://github.com/PricelessToolkit/MailBoxGuard/files/12425635/libraries.zip)

PricelessToolkit, 2023-08-24:
Error compiling for board ATtiny3226/3216/1626/1616/1606/826/816/806/426/416/406.
Library not working with Attiny1616

WhistleMaster, 2023-08-24:
This is where my competences with Arduino coding stop I guess. I'll leave you mastering it better than I could do 😄

PricelessToolkit, 2023-08-25:
I'm more into hardware than software so nop! 😊

WhistleMaster, 2023-08-31:
I've found another lib from Adafruit which could be good for OTAA. I'd need the following PINs.
- The Lora module's interrupt pin (rfm_nss).
- The Lora module's slave select pin (rfm_nss).
- The Lora module's reset pin (rfm_rst).

I had a look at the schematic but I'm not sure which pin of the Ai-Thinker-Ra you used.

Thanks !

PricelessToolkit, 2023-08-31:
ARDUINO | ATTINY | LORA

GPIO14 - PA1 - MOSI
GPIO15 - PA2 - MISO
GPIO16 -  PA3 - SCK/CLK
GPIO1 -  PA5 - RESET
GPIO10 - PC0 - NSS

WhistleMaster, 2023-09-01:
Thanks !

I have the NSS and the RST pins, but I still don't get what the interrupt pin is. Should be DI0 on the LoRa chip but to what pin on the ATTINY is it connected ?

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

PricelessToolkit, 2023-09-01:
DI0 is not connected, Since the sensor does not have a sleep mode "power is completely turned off" DI0 is not used. DI0 is used for two-way comunication "if I understand correctly". So DI0 is not required.

PricelessToolkit, 2023-09-01:
"The dio0 pin can be used for channel activity detection callback, transmission finish callback and/or receiving callback, check onCadDone , onTxDone, and onReceive."

WhistleMaster, 2023-09-14:
So what would be the module's interrupt pin ?

WhistleMaster, 2023-10-01:
Is this closed because the sensor has now the OTAA function ?

PricelessToolkit, 2023-10-01:
I closed it because of inactivity + the interrupt pin is not connected to the LoRa module.

WhistleMaster, 2023-10-17:
Well, we can keep it open, just in case someone is interested to jump in to help :)

PricelessToolkit, 2023-10-17:
ok

WhistleMaster, 2023-10-18:
I've done other tests and unfortunately the TinyLora lib from Adafruit is not compatible with TTNv3... and it seems that there is no other lib working with the Attiny1616...

PricelessToolkit, 2023-10-18:
Hi, if i understand correctly TTN uses one-way communication, then why all TTN libs require DI0 I can't understand.

WhistleMaster, 2023-10-19:
It seems to be related to single-channel packet forwarders that no longer work after the Things Network migration to The Things Stack v3. according to that forum thread: https://www.thethingsnetwork.org/forum/t/single-channel-packet-forwarders-scpf-are-deprecated-and-not-supported/31117

WhistleMaster, 2023-12-05:
I found the following project https://github.com/novag/LoRa-ATtiny-Node, for ATtiny85, which implements the ABP and OTAA.

Maybe that could also work with the Attiny1616 ?

PricelessToolkit, 2023-12-06:
Autor says "Currently this library is heavily optimized for ATtiny85 chips and needs changes to run on other devices" + "It has support for downlink messages" it uses "DI0" too,  so I don't think it will work.

WhistleMaster, 2023-12-09:
That's a pity... I found somewhere that you could also achieve the OTAA by sending AT commands, such as the following:

```
AT+CJOINMODE=0
AT+CRXP=1,1,869525000
AT+CDEVEUI=70B3D57ED0052256
AT+CAPPEUI=0000000000000000
AT+CAPPKEY=8D5EC8F6834BDE677A3D815E81A14981
AT+CFREQBANDMASK=0001
AT+CULDLMODE=2
AT+CJOIN=1,1,8,8
AT+DTRX=0,2,6,445566
AT+DTRX=1,1,4,5555
```

Is that something that could be supported by the lora chip you use ?

PricelessToolkit, 2023-12-09:
Hi, unfortunately, no! These AT commands for assemblies like the "MCU+LoRa"  stand-alone LoRa chip can't support AT commands, "it does not speak TTL"

itopaloglu83, 2024-01-29:
I was about to ask about the same The Things Network (TTN) support when I found this issue. It is quite unfortunate that we are not able to make it work.  Thank you for all the research and experimentation.

Could you provide a summary of what the problem is? I'm not very familiar with the requirements for TTN so I would like to research it a little bit more. The form link about talks about packet forwarders but my understanding is that MailBoxGuard would be an end node only.

PricelessToolkit, 2024-01-29:
The problem is that this sensor was not designed to work with TTN, "I didn't know that to work with TTN" I needed to connect the DI0 LoRa pin to an interrupt-capable MCU pin. "it is for detecting when the transmission is done" TTN libraries require this connection, but I don't know why....

itopaloglu83, 2024-01-30:
First of all, you did a great job with the board and the video. I already bought one and now experimenting to see if I can get away with not having a gateway and use TTN instead. It's a fun side project to tinker with.

Arduino LoRa library says that the DIO0 is optional and it is only needed for the receive callback mode. I also remember watching Andreas Spiess' video about the MailboxNotifier, he used the interrupt to keep the MCU sleeping while the packets were being sent.

I'm going to read the sample codes above and see if there's any walk around.

itopaloglu83, 2024-02-02:
This update is for any future curious souls. After experimenting with an OTAA capable board for a while and realizing that there is no TTN gateway close to where I live, I abandoned figuring out how to connect MailboxGuard to TTN.

PricelessToolkit, 2024-02-02:
> This update is for any future curious souls. After experimenting with an OTAA capable board for a while and realizing that there is no TTN gateway close to where I live, I abandoned figuring out how to connect MailboxGuard to TTN.

Thanks for trying, I don't have a close gateway either.

WhistleMaster, 2024-02-02:
I do have a gateway and would be really happy to test !

itopaloglu83, 2024-02-02:
I don't have an exact procedure to follow but here's the approach I was planning to take.

Practically speaking, the interrupt functionality is only needed when the LoRa Radio module is receiving a package and needs to inform the microcontroller about it. This is required because during OTAA setup, various back-and-forward communication takes place to exchange encryption keys etc. One could theoretically make a small sketch that registers to the TTN network by sending the required messages (APPID etc.) and then polling for a response from the radio instead of using the interrupts. In a way, writing an alternative LoRaWan library that can work on AtTiny1616.

If you just want to experiment without writing your own LoRaWan library, you can try something like [Dragino LDS02](https://www.dragino.com/products/lorawan-nb-iot-door-sensor-water-leak/item/181-lds02.html) that is already capable of joining TTN via OTAA.

WhistleMaster, 2024-02-05:
Yes, indeed, we could use another sensor from Dragino but it would be better to use the MailBoxGuard 🙂

PricelessToolkit, 2024-06-22:
All will be fixed with the next HW version.

Closed 2024-06-22.

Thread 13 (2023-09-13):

Documentation on how to seperate the battery charger

frederickjh, 2023-09-13:
Hello,
I am interested in your project and see that one of the features listed in the READMEmd file is that the battery charger can be separated.

This would be ideal for my use case at a mailbox service where I get my mail. That way I could have two batteries and charge them at home switching them when the battery in use get low.

However I cannot seem to find any documentation regarding how this work. Plus it looks like the one battery contact is on the back of the charger board.

Sorry if I somehow missed the documentation on this in my search.
Thanks for your project and help!
Frederick

PricelessToolkit, 2023-09-18:
Hi,
This feature is more for those who solder board themselves. instead of soldering the 14500 battery holders you need to solder a small 1s lipo connector, and just cut the board in the middle of the two lines. The battery will not run out quickly, you have plenty of time, it’s better to remove the sensor in the evening, charge it, and put it back in the morning, in my opinion, it’s unlikely that you receive new mail at night.  But if you still want to charge the second battery I added the link for a cheap charger ~$3.

Regards

Closed 2023-09-21.

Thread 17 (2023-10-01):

Error when compiling

Gahrlaag, 2023-10-01:
C:\Program Files (x86)\Arduino\arduino-builder -dump-prefs -logger=machine -hardware C:\Program Files (x86)\Arduino\hardware -hardware C:\Users\Aleks\AppData\Local\Arduino15\packages -tools C:\Program Files (x86)\Arduino\tools-builder -tools C:\Program Files (x86)\Arduino\hardware\tools\avr -tools C:\Users\Aleks\AppData\Local\Arduino15\packages -built-in-libraries C:\Program Files (x86)\Arduino\libraries -libraries C:\Users\Aleks\Documents\Arduino\libraries -fqbn=megaTinyCore:megaavr:atxy6:chip=1616,clock=5internal,bodvoltage=1v8,bodmode=disabled,eesave=enable,millis=enabled,resetpin=UPDI,startuptime=8,wiremode=mors,printf=default,PWMmux=A_default,attach=allenabled,WDTtimeout=disabled,WDTwindow=disabled -vid-pid=1A86_7523 -ide-version=10813 -build-path C:\Users\Aleks\AppData\Local\Temp\arduino_build_809065 -warnings=none -build-cache C:\Users\Aleks\AppData\Local\Temp\arduino_cache_912473 -prefs=build.warn_data_percentage=75 -prefs=runtime.tools.avr-gcc.path=C:\Users\Aleks\AppData\Local\Arduino15\packages\DxCore\tools\avr-gcc\7.3.0-atmel3.6.1-azduino6 -prefs=runtime.tools.avr-gcc-7.3.0-atmel3.6.1-azduino6.path=C:\Users\Aleks\AppData\Local\Arduino15\packages\DxCore\tools\avr-gcc\7.3.0-atmel3.6.1-azduino6 -prefs=runtime.tools.arduinoOTA.path=C:\Users\Aleks\AppData\Local\Arduino15\packages\arduino\tools\arduinoOTA\1.3.0 -prefs=runtime.tools.arduinoOTA-1.3.0.path=C:\Users\Aleks\AppData\Local\Arduino15\packages\arduino\tools\arduinoOTA\1.3.0 -prefs=runtime.tools.avrdude.path=C:\Users\Aleks\AppData\Local\Arduino15\packages\DxCore\tools\avrdude\6.3.0-arduino17or18 -prefs=runtime.tools.avrdude-6.3.0-arduino17or18.path=C:\Users\Aleks\AppData\Local\Arduino15\packages\DxCore\tools\avrdude\6.3.0-arduino17or18 -prefs=runtime.tools.python3.path=C:\Users\Aleks\AppData\Local\Arduino15\packages\megaTinyCore\tools\python3\3.7.2-post1 -prefs=runtime.tools.python3-3.7.2-post1.path=C:\Users\Aleks\AppData\Local\Arduino15\packages\megaTinyCore\tools\python3\3.7.2-post1 -verbose C:\Users\Aleks\Desktop\MailBoxGuard-main\Code\Arduino\Mailbox_Guard_Sensor\Mailbox_Guard_Sensor.ino
C:\Program Files (x86)\Arduino\arduino-builder -compile -logger=machine -hardware C:\Program Files (x86)\Arduino\hardware -hardware C:\Users\Aleks\AppData\Local\Arduino15\packages -tools C:\Program Files (x86)\Arduino\tools-builder -tools C:\Program Files (x86)\Arduino\hardware\tools\avr -tools C:\Users\Aleks\AppData\Local\Arduino15\packages -built-in-libraries C:\Program Files (x86)\Arduino\libraries -libraries C:\Users\Aleks\Documents\Arduino\libraries -fqbn=megaTinyCore:megaavr:atxy6:chip=1616,clock=5internal,bodvoltage=1v8,bodmode=disabled,eesave=enable,millis=enabled,resetpin=UPDI,startuptime=8,wiremode=mors,printf=default,PWMmux=A_default,attach=allenabled,WDTtimeout=disabled,WDTwindow=disabled -vid-pid=1A86_7523 -ide-version=10813 -build-path C:\Users\Aleks\AppData\Local\Temp\arduino_build_809065 -warnings=none -build-cache C:\Users\Aleks\AppData\Local\Temp\arduino_cache_912473 -prefs=build.warn_data_percentage=75 -prefs=runtime.tools.avr-gcc.path=C:\Users\Aleks\AppData\Local\Arduino15\packages\DxCore\tools\avr-gcc\7.3.0-atmel3.6.1-azduino6 -prefs=runtime.tools.avr-gcc-7.3.0-atmel3.6.1-azduino6.path=C:\Users\Aleks\AppData\Local\Arduino15\packages\DxCore\tools\avr-gcc\7.3.0-atmel3.6.1-azduino6 -prefs=runtime.tools.arduinoOTA.path=C:\Users\Aleks\AppData\Local\Arduino15\packages\arduino\tools\arduinoOTA\1.3.0 -prefs=runtime.tools.arduinoOTA-1.3.0.path=C:\Users\Aleks\AppData\Local\Arduino15\packages\arduino\tools\arduinoOTA\1.3.0 -prefs=runtime.tools.avrdude.path=C:\Users\Aleks\AppData\Local\Arduino15\packages\DxCore\tools\avrdude\6.3.0-arduino17or18 -prefs=runtime.tools.avrdude-6.3.0-arduino17or18.path=C:\Users\Aleks\AppData\Local\Arduino15\packages\DxCore\tools\avrdude\6.3.0-arduino17or18 -prefs=runtime.tools.python3.path=C:\Users\Aleks\AppData\Local\Arduino15\packages\megaTinyCore\tools\python3\3.7.2-post1 -prefs=runtime.tools.python3-3.7.2-post1.path=C:\Users\Aleks\AppData\Local\Arduino15\packages\megaTinyCore\tools\python3\3.7.2-post1 -verbose C:\Users\Aleks\Desktop\MailBoxGuard-main\Code\Arduino\Mailbox_Guard_Sensor\Mailbox_Guard_Sensor.ino
Using board 'atxy6' from platform in folder: C:\Users\Aleks\AppData\Local\Arduino15\packages\megaTinyCore\hardware\megaavr\2.6.8
Using core 'megatinycore' from platform in folder: C:\Users\Aleks\AppData\Local\Arduino15\packages\megaTinyCore\hardware\megaavr\2.6.8
Detecting libraries used...
"C:\\Users\\Aleks\\AppData\\Local\\Arduino15\\packages\\DxCore\\tools\\avr-gcc\\7.3.0-atmel3.6.1-azduino6/bin/avr-g++" -c -g -Os -Wall -std=gnu++17 -fpermissive -Wno-sized-deallocation -fno-exceptions -ffunction-sections -fdata-sections -fno-threadsafe-statics -Wno-error=narrowing -flto -mrelax -w -x c++ -E -CC -mmcu=attiny1616 -DF_CPU=5000000L -DCLOCK_SOURCE=0 -DTWI_MORS -DMILLIS_USE_TIMERD0 -DCORE_ATTACH_ALL -DUSE_TIMERD0_PWM -DARDUINO=10813 -DARDUINO_AVR_ATtiny1616 -DARDUINO_ARCH_MEGAAVR "-DMEGATINYCORE=\"2.6.8.1\"" -DMEGATINYCORE_MAJOR=2UL -DMEGATINYCORE_MINOR=6UL -DMEGATINYCORE_PATCH=8UL -DMEGATINYCORE_RELEASED=1 -DARDUINO_attinyxy6 "-IC:\\Users\\Aleks\\AppData\\Local\\Arduino15\\packages\\megaTinyCore\\hardware\\megaavr\\2.6.8\\cores\\megatinycore/api/deprecated" "-IC:\\Users\\Aleks\\AppData\\Local\\Arduino15\\packages\\megaTinyCore\\hardware\\megaavr\\2.6.8\\cores\\megatinycore" "-IC:\\Users\\Aleks\\AppData\\Local\\Arduino15\\packages\\megaTinyCore\\hardware\\megaavr\\2.6.8\\variants\\txy6" "C:\\Users\\Aleks\\AppData\\Local\\Temp\\arduino_build_809065\\sketch\\Mailbox_Guard_Sensor.ino.cpp" -o nul -DARDUINO_LIB_DISCOVERY_PHASE
Alternatives for SPI.h: [SPI@1.1.2]
ResolveLibrary(SPI.h)
  -> candidates: [SPI@1.1.2]
"C:\\Users\\Aleks\\AppData\\Local\\Arduino15\\packages\\DxCore\\tools\\avr-gcc\\7.3.0-atmel3.6.1-azduino6/bin/avr-g++" -c -g -Os -Wall -std=gnu++17 -fpermissive -Wno-sized-deallocation -fno-exceptions -ffunction-sections -fdata-sections -fno-threadsafe-statics -Wno-error=narrowing -flto -mrelax -w -x c++ -E -CC -mmcu=attiny1616 -DF_CPU=5000000L -DCLOCK_SOURCE=0 -DTWI_MORS -DMILLIS_USE_TIMERD0 -DCORE_ATTACH_ALL -DUSE_TIMERD0_PWM -DARDUINO=10813 -DARDUINO_AVR_ATtiny1616 -DARDUINO_ARCH_MEGAAVR "-DMEGATINYCORE=\"2.6.8.1\"" -DMEGATINYCORE_MAJOR=2UL -DMEGATINYCORE_MINOR=6UL -DMEGATINYCORE_PATCH=8UL -DMEGATINYCORE_RELEASED=1 -DARDUINO_attinyxy6 "-IC:\\Users\\Aleks\\AppData\\Local\\Arduino15\\packages\\megaTinyCore\\hardware\\megaavr\\2.6.8\\cores\\megatinycore/api/deprecated" "-IC:\\Users\\Aleks\\AppData\\Local\\Arduino15\\packages\\megaTinyCore\\hardware\\megaavr\\2.6.8\\cores\\megatinycore" "-IC:\\Users\\Aleks\\AppData\\Local\\Arduino15\\packages\\megaTinyCore\\hardware\\megaavr\\2.6.8\\variants\\txy6" "-IC:\\Users\\Aleks\\AppData\\Local\\Arduino15\\packages\\megaTinyCore\\hardware\\megaavr\\2.6.8\\libraries\\SPI\\src" "C:\\Users\\Aleks\\AppData\\Local\\Temp\\arduino_build_809065\\sketch\\Mailbox_Guard_Sensor.ino.cpp" -o nul -DARDUINO_LIB_DISCOVERY_PHASE
Alternatives for LoRa.h: [LoRa@0.8.0]
ResolveLibrary(LoRa.h)
  -> candidates: [LoRa@0.8.0]
"C:\\Users\\Aleks\\AppData\\Local\\Arduino15\\packages\\DxCore\\tools\\avr-gcc\\7.3.0-atmel3.6.1-azduino6/bin/avr-g++" -c -g -Os -Wall -std=gnu++17 -fpermissive -Wno-sized-deallocation -fno-exceptions -ffunction-sections -fdata-sections -fno-threadsafe-statics -Wno-error=narrowing -flto -mrelax -w -x c++ -E -CC -mmcu=attiny1616 -DF_CPU=5000000L -DCLOCK_SOURCE=0 -DTWI_MORS -DMILLIS_USE_TIMERD0 -DCORE_ATTACH_ALL -DUSE_TIMERD0_PWM -DARDUINO=10813 -DARDUINO_AVR_ATtiny1616 -DARDUINO_ARCH_MEGAAVR "-DMEGATINYCORE=\"2.6.8.1\"" -DMEGATINYCORE_MAJOR=2UL -DMEGATINYCORE_MINOR=6UL -DMEGATINYCORE_PATCH=8UL -DMEGATINYCORE_RELEASED=1 -DARDUINO_attinyxy6 "-IC:\\Users\\Aleks\\AppData\\Local\\Arduino15\\packages\\megaTinyCore\\hardware\\megaavr\\2.6.8\\cores\\megatinycore/api/deprecated" "-IC:\\Users\\Aleks\\AppData\\Local\\Arduino15\\packages\\megaTinyCore\\hardware\\megaavr\\2.6.8\\cores\\megatinycore" "-IC:\\Users\\Aleks\\AppData\\Local\\Arduino15\\packages\\megaTinyCore\\hardware\\megaavr\\2.6.8\\variants\\txy6" "-IC:\\Users\\Aleks\\AppData\\Local\\Arduino15\\packages\\megaTinyCore\\hardware\\megaavr\\2.6.8\\libraries\\SPI\\src" "-IC:\\Users\\Aleks\\Documents\\Arduino\\libraries\\LoRa\\src" "C:\\Users\\Aleks\\AppData\\Local\\Temp\\arduino_build_809065\\sketch\\Mailbox_Guard_Sensor.ino.cpp" -o nul -DARDUINO_LIB_DISCOVERY_PHASE
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
PricelessToolkit, 2023-10-01:
Hi,
1. Arduino IDE version?
2. Download "Mailbox_Guard_Sensor_HARestAPI.ino" don't just copy past it

Gahrlaag, 2023-10-01:
1. 2.2.1
2. I haven't copypasted anything. I downloaded the entire zip from the main github, including "Mailbox_Guard_Sensor_HARestAPI.ino" and "Mailbox_Guard_Sensor.ino"

PricelessToolkit, 2023-10-01:
https://github.com/PricelessToolkit/MailBoxGuard#arduino-setup-ide-20x-unsupported

Gahrlaag, 2023-10-01:
> https://github.com/PricelessToolkit/MailBoxGuard#arduino-setup-ide-20x-unsupported

Not following? All of the libraries are present and the correct board is selected.

PricelessToolkit, 2023-10-01:
Arduino "IDE 2.0.x is unsupported, its a "megaTinyCore" Recommendation

PricelessToolkit, 2023-10-01:
I am using 1.8.19 and the code compiles without any problems

Gahrlaag, 2023-10-01:
I just tried 1.8.57.0 and I get the same error. Exact same settings

Gahrlaag, 2023-10-01:
Same with 1.8.19

PricelessToolkit, 2023-10-01:
Do you modify the code?

I think it is a TAB or ESPACE issue try highlighting all the text in the IDE
Select Tools > AutoFormat

PricelessToolkit, 2023-10-01:
you get errors like this

`loop()' previously defined here
void loop() {
^~~~`

only if you messed up with the formatting text

Gahrlaag, 2023-10-01:
> Do you modify the code?
>
> I think it is a TAB or ESPACE issue try highlighting all the text in the IDE Select Tools > AutoFormat

I havent touched the code aside from changing the values of NewMailCode and LowBatteryCode.

here's a pastebin of the exact code

https://pastebin.com/cA2nHuq5

PricelessToolkit, 2023-10-01:
Pastebin code compiled widout problem. you have problem with your Arduino installation

Gahrlaag, 2023-10-01:
> Pastebin code compiled widout problem. you have problem with your Arduino installation

I've tried it on two different computers :D WTF....

Gahrlaag, 2023-10-01:
Is there a library missing? prerequisites?

PricelessToolkit, 2023-10-01:
only these
#include <SPI.h>
#include <LoRa.h>
#include <avr/sleep.h>

did you install the libraries or use those from the project?

Gahrlaag, 2023-10-01:
I installed them.. should I use the ones from the project?

PricelessToolkit, 2023-10-01:
I am using libraries from the project

PricelessToolkit, 2023-10-01:
and one stupid question, in the sketch folder is there only one ".ino" file?

Gahrlaag, 2023-10-01:
> and one stupid question, in the sketch folder is there only one ".ino" file?

Goddammit I'm stupid... No, of course not.
Compiles as it should now... D'oh

Closed 2023-10-01.

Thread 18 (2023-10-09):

Inject 3.3v to an unpowered LDO output?

pavel-d, 2023-10-09:
Hey @PricelessToolkit, I'm curious if there are any risk when powering the board directly via 3.3v programming pad. The SPX3819's output is directly connected to 3.3v rail (there are no diodes or other components in between), so it will have a 3.3v on the OUT, and 0v on the input. Are there any risk damaging the LDO? I haven't found anything in the datasheet unfortunately

PricelessToolkit, 2023-10-09:
Hi, yes, you can, when you are programming MailBox Guard you doing exactly the same thing.

pavel-d, 2023-10-09:
There is an opinion on the internet that not all LDOs like that and I wasn’t able to find any evidence that the SPX3819 handles it. But it’s good to know that it works fine!

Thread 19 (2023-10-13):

question regarding setup

steuerzentrale, 2023-10-13:
first of all many thanks for this nice piece of hardware, it is EXACTLY what i have been looking for! I am about to order the mailbox-sensor from your shop and already looked on how to configure everything. I have some knowledge on ESPHome but only a very basic understanding of Arduino IDE. lets come to my question.

I configured LoRa_Gateway_MQTT.ino with my credentials (Wifi and MQTT) as well as LoRa_Gateway_HARestAPI.ino (with the token). I dont understand what to do with the sketches afterwards.

Do I have to combine them in order to upload it on the TTGO board or do I have to upload the LoRa_Gateway_MQTT.ino first and then LoRa_Gateway_HARestAPI.ino?

Sorry for my noob-question, I couldnt find an answer in the readme.

PricelessToolkit, 2023-10-13:
Hi, do you want to use the MQTT version or RestAPI?

If MQTT then
`"Mailbox_Guard_Sensor_MQTT_Auto_Discovery.ino" ` goes into the sensor,

`"LoRa_Gateway_MQTT_Auto_Discovery.ino" and "board.h"` into Gateway

steuerzentrale, 2023-10-13:
thanks for the quick reply, I want to use MQTT. Now I get it, i thought I had to use LoRa_Gateway_MQTT.ino AND LoRa_Gateway_HARestAPI.ino but yeah, at the time of writing I understand that the sensors infos pass through MQTT which is running on my HA-instance.

Closed 2023-10-13.

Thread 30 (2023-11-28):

Request: add SNR

steuerzentrale, 2023-11-28:
Hi there

is it possible to add the SNR-value in addition to the RSSI which is already being reported? This would help to determine if the connection is good. At the moment I have an RSSI between -98dbm and -107dbm but I dont know the SNR to evaluate if the connection is good or I should reposition the sensor.

all the best, Andrew

PricelessToolkit, 2023-12-16:
Mailbox_Guard_Sensor_HARestAPI reporting SNR, but in your place, I wouldn't even worry about SNR.. the best thing you can do is to change the gateway antenna.

Closed 2023-12-16.

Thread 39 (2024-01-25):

PIR Sensitivity + Door contact sensor

RubenWaterman, 2024-01-25:
First of all, awesome project and thanks very much! I've got it successfully integrated in my Loxone smart home 🤩
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

For some reason, the on-board PIR triggers way too often, when there is no mail inserted. Is there a configuration flag to make the PIR less sensitive?

I was also thinking of soldering a door contact on board (and either attach on the slat that opens when mail is inserted to trigger the "new mail" activity, OR to put the door contact on the actual door so that would trigger the "I've seen the mail" event). I found the correct pins for this on the board but I didn't find any code on how to set this up. Do you happen to have an example for this?

RubenWaterman, 2024-01-25:
Ah, is it possible to trigger two separate types of MQTT messages, i.e. one for PIR activity and one for door contact sensor?

WhistleMaster, 2024-01-25:
I don't think so. The PIR and the door contact switch are both used as trigger on the board.

PricelessToolkit, 2024-01-25:
Thank you for supporting my work.
"For some reason, the on-board PIR triggers way too often" If you have a mailbox with a small slit for mail and it stays open, change the location of the sensor so that the sensor faces in the other direction.

Closed 2024-02-10.

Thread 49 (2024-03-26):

Screen is always blank

dmfrey, 2024-03-26:
I've uploaded numerous times your lora gateway code, specifically, the MQTT HA ones. Should I see anything on the screen after it uploads? I can see the device on the network.

Also, side note, the MQTT user and password, should they be the HA MQTT User and Password?  I ended up creating a new user for this specifically. But I'm guessing it should be the HA one.

dmfrey, 2024-03-26:
Regarding my side note, I updated it to the HA MQTT User and Password and now I see the entities in HA. That can be disregarded.

PricelessToolkit, 2024-03-26:
Hi, Only the ( LoRa_Gateway_OLED "Standalone" ) firmware utilizes OLED.

dmfrey, 2024-03-26:
@PricelessToolkit Ah, makes sense. I guess I assumed it was gonna do something. I was able to get it up and running an HA recognized it. Now I'm just waiting on the sensor to try it out :)

dmfrey, 2024-03-26:
closes #49

Closed 2024-03-26.

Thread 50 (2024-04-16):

VDD was not declared in this scope

dmfrey, 2024-04-16:
Please bare with me, i'm new to arduino

I'm attempting to build the Mailbox_Guard_Sensor and I'm getting the following error:

```
Arduino: 1.8.19 (Mac OS X), Board: "ESP32 Dev Module, Disabled, Disabled, Default 4MB with spiffs (1.2MB APP/1.5MB SPIFFS), 240MHz (WiFi/BT), QIO, 80MHz, 4MB (32Mb), 115200, Core 1, Core 1, Debug, Disabled"

/Users/dfrey/Development/git/PricelessToolkit/MailBoxGuard/Code/Arduino/Mailbox_Guard_Sensor/Mailbox_Guard_Sensor/Mailbox_Guard_Sensor.ino: In function 'void setup()':
Mailbox_Guard_Sensor:29:19: error: 'VDD' was not declared in this scope
   analogReference(VDD);
                   ^~~
Mailbox_Guard_Sensor:29:3: error: 'analogReference' was not declared in this scope
   analogReference(VDD);
   ^~~~~~~~~~~~~~~
/Users/dfrey/Development/git/PricelessToolkit/MailBoxGuard/Code/Arduino/Mailbox_Guard_Sensor/Mailbox_Guard_Sensor/Mailbox_Guard_Sensor.ino:29:3: note: suggested alternative: 'analogGetChannel'
   analogReference(VDD);
   ^~~~~~~~~~~~~~~
   analogGetChannel
/Users/dfrey/Development/git/PricelessToolkit/MailBoxGuard/Code/Arduino/Mailbox_Guard_Sensor/Mailbox_Guard_Sensor/Mailbox_Guard_Sensor.ino: In function 'void loop()':
Mailbox_Guard_Sensor:54:31: error: 'PIN_PB4' was not declared in this scope
   float volts = analogReadEnh(PIN_PB4, 12)*(1.1/4096)*(30+10)/10;
                               ^~~~~~~
/Users/dfrey/Development/git/PricelessToolkit/MailBoxGuard/Code/Arduino/Mailbox_Guard_Sensor/Mailbox_Guard_Sensor/Mailbox_Guard_Sensor.ino:54:31: note: suggested alternative: 'PIN_DAC2'
   float volts = analogReadEnh(PIN_PB4, 12)*(1.1/4096)*(30+10)/10;
                               ^~~~~~~
                               PIN_DAC2
Mailbox_Guard_Sensor:54:17: error: 'analogReadEnh' was not declared in this scope
   float volts = analogReadEnh(PIN_PB4, 12)*(1.1/4096)*(30+10)/10;
                 ^~~~~~~~~~~~~
/Users/dfrey/Development/git/PricelessToolkit/MailBoxGuard/Code/Arduino/Mailbox_Guard_Sensor/Mailbox_Guard_Sensor/Mailbox_Guard_Sensor.ino:54:17: note: suggested alternative: 'analogRead'
   float volts = analogReadEnh(PIN_PB4, 12)*(1.1/4096)*(30+10)/10;
                 ^~~~~~~~~~~~~
                 analogRead
Mailbox_Guard_Sensor:87:20: error: 'SLEEP_MODE_PWR_DOWN' was not declared in this scope
     set_sleep_mode(SLEEP_MODE_PWR_DOWN);
                    ^~~~~~~~~~~~~~~~~~~
Mailbox_Guard_Sensor:87:5: error: 'set_sleep_mode' was not declared in this scope
     set_sleep_mode(SLEEP_MODE_PWR_DOWN);
     ^~~~~~~~~~~~~~
Mailbox_Guard_Sensor:88:5: error: 'sleep_enable' was not declared in this scope
     sleep_enable();
     ^~~~~~~~~~~~
/Users/dfrey/Development/git/PricelessToolkit/MailBoxGuard/Code/Arduino/Mailbox_Guard_Sensor/Mailbox_Guard_Sensor/Mailbox_Guard_Sensor.ino:88:5: note: suggested alternative: 'spiSSEnable'
     sleep_enable();
     ^~~~~~~~~~~~
     spiSSEnable
Mailbox_Guard_Sensor:89:5: error: 'sleep_mode' was not declared in this scope
     sleep_mode();  // Now enter sleep mode.
     ^~~~~~~~~~
/Users/dfrey/Development/git/PricelessToolkit/MailBoxGuard/Code/Arduino/Mailbox_Guard_Sensor/Mailbox_Guard_Sensor/Mailbox_Guard_Sensor.ino:89:5: note: suggested alternative: 'sleep'
     sleep_mode();  // Now enter sleep mode.
     ^~~~~~~~~~
     sleep
exit status 1
'VDD' was not declared in this scope

This report would have more information with
"Show verbose output during compilation"
option enabled in File -> Preferences.
```

I'm guessing it has to do with the board selected, which is currently the lora gateway board. I'm not really sure what to set it to for the universal programmer. A lot of these look like they're functions that haven't been imported in the header.

Thank you for your help.

PricelessToolkit, 2024-04-16:
Hi,

Select Board type "ATTiny1616 5MHz" https://github.com/PricelessToolkit/MailBoxGuard?tab=readme-ov-file#mailbox-sensor-configuration

dmfrey, 2024-04-16:
Thank you. I'm not seeing that board in the board manager. Is there a specific one I need to install?

PricelessToolkit, 2024-04-16:
You need to install "megaTinyCore" library, it will add ATTiny support. So add this link to Boards Manager "http://drazzy.com/package_drazzy.com_index.json"

https://github.com/PricelessToolkit/MailBoxGuard?tab=readme-ov-file#arduino-setup-ide-20x-unsupported

dmfrey, 2024-04-16:
Thank you for your help. I think I'm getting close to getting the code to verify in the ide. There seems to be one more exception:
```
Arduino: 1.8.19 (Mac OS X), Board: "ATtiny3226/3216/1626/1616/1606/826/816/806/426/416/406, ATtiny1616, 5 MHz internal, 1.8V (5 MHz or less), Disabled/Disabled, EEPROM retained, Enabled (default timer), UPDI (no reset pin), 8ms, Master or Slave (saves flash and RAM), Default (doesn't print floats, 1.4k flash use), PB0-2, PA3-5, 1-series: PC0/1 (default), On all pins, with new implementation., Disabled (recommended), No delay before window "opens""

/Users/dfrey/Development/git/PricelessToolkit/MailBoxGuard/Code/Arduino/Mailbox_Guard_Sensor/Mailbox_Guard_Sensor/Mailbox_Guard_Sensor.ino: In function 'void loop()':
Mailbox_Guard_Sensor:87:5: error: 'set_sleep_mode' was not declared in this scope
     set_sleep_mode(SLEEP_MODE_PWR_DOWN);
     ^~~~~~~~~~~~~~
Mailbox_Guard_Sensor:88:5: error: 'sleep_enable' was not declared in this scope
     sleep_enable();
     ^~~~~~~~~~~~
Mailbox_Guard_Sensor:89:5: error: 'sleep_mode' was not declared in this scope
     sleep_mode();  // Now enter sleep mode.
     ^~~~~~~~~~
exit status 1
'set_sleep_mode' was not declared in this scope

This report would have more information with
"Show verbose output during compilation"
option enabled in File -> Preferences.
```

dmfrey, 2024-04-17:
I noticed that this include was commented out:
```
#include <avr/sleep.h>
```
I uncommented it and now it compiles. Not sure if I did that or not.

dmfrey, 2024-04-17:
Just checked the code in the repo and it is commented out. Is that intended? Where does that function come from then? Am I missing an included library somewhere?

dmfrey, 2024-04-17:
I got it working. thank you for your help.

PricelessToolkit, 2024-04-17:
> Just checked the code in the repo and it is commented out. Is that intended? Where does that function come from then? Am I missing an included library somewhere?

Hi, I can't explain why it was commented out; it was an error on my part. I will uncomment it. Thanks for pointing it out.

Closed 2024-04-17.

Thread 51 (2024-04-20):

Question: Is there a way to set up a second reed switch to reset the counter to zero when opening the mailbox?

ndbroadbent, 2024-04-20:
Hello, thanks for the awesome design! I ordered one a while ago and it's been working very well. I 3D printed a custom flap with magnets for my mailbox, so it triggers a reed switch when a letter opens the flap.

There's just one small feature that I would like to add. It would be great if I could get the mailbox sensor to send a "reset count" message whenever I open the main door on our mailbox to collect the mail. I could add a second reed switch on the main door, but I'm wondering if there's a spare GPIO pin somewhere that I could use for this purpose.

If not, how difficult would it be to update the PCB design? I would be happy to order a second sensor if this feature was added. Thanks a lot!

PricelessToolkit, 2024-04-20:
Hi, thanks for supporting my work!!, no, unfortunately, there is no way to add that functionality to the current version. I am already working on the new version :) and I will make sure to add GPIO pins specially for that purpose.

schweighart, 2024-11-04:
I'm thinking about adding a reed switch between the battery and the board. With that it would cut off power whenever the door is opened to collect the mail. Then the board could send the mailbox empty signal in the init block when the power is coming back. The signal from the pir sensor would also need a delay of a few seconds to not trigger the new mail event before the power is cut off.
I assume I just need a powerful enough reed switch to support the initial power spike. Did I miss something else in my idea?

PricelessToolkit, 2024-11-04:
It won't work because the ATtiny is powered off most of the time, and the trigger relies on physical circuitry. The sensor needs to distinguish between the first activation after power-on and a signal from the PIR sensor, which is impossible with the current hardware version.

schweighart, 2024-11-06:
I totally forgot in my thoughts that the ATtiny is powered down. I somehow had the impression that it is only sleeping. I'm still not willing to give up and came up with 2 other ideas:
1) Cut the connection to the PIR sensor on the back and use a reed sensor instead of the permanent connection. With that the PIR sensor would be cut off as soon as the mailbox door is opened. With the hope that PIR is not faster in triggering.
2) Repurpose the RX or TX connector for the reed sensor. The PIR sensor would still wake up the board but the code could check (probably with a small delay) the state of the reed sensor to know which message to send. The documentation lists these pins also as GPIO but I'm not sure if they would really work as that.

Soldering a tiny wire to a spare pin of the ATtiny seems to be impossible. I also thought about forceful reset the LoRa module from the outside to prevent sending, but I think that would cause other issues without a diode protection the current circuit.

PricelessToolkit, 2024-11-06:
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

If you'd like to try a DIY approach, you might want to wait for the next version, which i hope will include three inputs + pir. With those, you'll be able to create more versatile logic setups.

schweighart, 2024-11-09:
No need to wait for the next version :-) . I can confirm that it works. I'll put some instructions here for the next one:
I've soldered my reed sensor (door sensor) between ground and RX (TX would also work).
In the code I've removed all Serial. commands as they would use the same pins.
In the setup block I initialize the pin with:
`pinMode(PIN_PB3, INPUT_PULLUP); `
(TX would be PIN_PB2). There I also added a 500ms delay to ensure the door magnet is already disconnected when the PIR sensor is triggered.
In the loop part I check if the door is open with the following if statement and I just send an alternative message.
```
if (digitalRead(PIN_PB3)==LOW) {
   //Door closed -> new mail
   LoRa.print(NewMailCode);
} else {
   //Door open -> mail collected
   LoRa.print(ClearMailCode);
}
```

PricelessToolkit, 2024-11-10:
Nice !! Do you have 2 doors in your mailbox?

schweighart, 2024-11-10:
No just a normal mailbox with a lid for the postman and a door at the back for me. The board with the PIR sensor is attached with magnets to the back door and is looking to the front lid.
With that the PIR is waking up on lid movement or back door movement. That's where I needed to distinguish what happend.

schweighart, 2024-11-19:
I had to chance my code a bit. I totally overestimated the time it takes to open the mailbox door in case nothing is in. I'm now checking more often the state of the reed sensor and also removed the delay.

```
#include <SPI.h>
#include <LoRa.h>
#include <avr/sleep.h>

//////////////////////////////////// CONFIG /////////////////////////////////////////////

#define SignalBandwidth 125E3
#define SpreadingFactor 12
#define CodingRate 8
#define SyncWord 0xF3
#define PreambleLength 8
#define TxPower 20
#define BAND 868E6     // frequency in Hz (ASIA 433E6, EU 868E6, US 915E6)
String NewMailCode = "0xA2B2"; // For Example "0xA2B2";
String ClearMailCode = "0xA2B3"; // For Example "0xA2B3";
String LowBatteryCode = "0xLBAT"; // For Example "0xLBAT";

/////////////////////////////////////////////////////////////////////////////////////////

int loopcounter = 0;
boolean doorOpen=false;
//Kept in Memory for about 10 seconds after shutdown. To prevent second sending.
int recentlyTriggered __attribute__((section(".noinit")));;

void setup() {
  pinMode(3, OUTPUT);
  digitalWrite(3, HIGH);
  analogReference(VDD);

  pinMode(PIN_PB2, INPUT_PULLUP); //TX
  pinMode(PIN_PB3, INPUT_PULLUP); //RX

  delay(5);

  for (int counter = 0; counter <= 500; counter++) {
    if (digitalRead(PIN_PB3)==HIGH) {
      doorOpen=true;
    }
    delay(10);
  }

  if (!LoRa.begin(BAND)) {
    while (1);
  }

  LoRa.setSignalBandwidth(SignalBandwidth); // signal bandwidth in Hz, defaults to 125E3
  LoRa.setSpreadingFactor(SpreadingFactor); // ranges from 6-12,default 7 see API docs
  LoRa.setCodingRate4(CodingRate);          // Supported values are between 5 and 8, these correspond to coding rates of 4/5 and 4/8. The coding rate numerator is fixed at 4.
  LoRa.setSyncWord(SyncWord);               // byte value to use as the sync word, defaults to 0x12
  LoRa.setPreambleLength(PreambleLength);   //Supported values are between 6 and 65535.
  LoRa.disableCrc();                        // Enable or disable CRC usage, by default a CRC is not used LoRa.disableCrc();
  LoRa.setTxPower(TxPower);                 // TX power in dB, defaults to 17, Supported values are 2 to 20

  if (recentlyTriggered==1) {
    shutdownAll();
  }

  for (int counter = 0; counter <= 500; counter++) {
    if (digitalRead(PIN_PB3)==HIGH) {
      doorOpen=true;
    }
    delay(10);
  }
}

void loop() {

  float volts = analogReadEnh(PIN_PB4, 12)*(1.1/4096)*(30+10)/10;
//  Serial.println(volts);

  if (loopcounter < 2){
    delay(50);
    LoRa.beginPacket();
    int perc = (int)constrain(((volts - 3.2) / (4.15 - 3.2)) * 100, 0, 100);
    if (doorOpen) {
      //Door open -> mail collected
      LoRa.print(ClearMailCode + "," + perc);
    } else {
      //Door closed -> new mail
      LoRa.print(NewMailCode + "," + perc);
    }
    LoRa.endPacket();
    delay (10);
    recentlyTriggered=1;
   }

  if (volts < 3.36 and loopcounter == 1 ){   // Don't change "3.36" !!
    LoRa.beginPacket();
    LoRa.print(LowBatteryCode);
    LoRa.endPacket();
    delay(50);
  }

  if(loopcounter > 2){
    shutdownAll();
  }

  loopcounter ++;
  delay(10);
}

void shutdownAll() {
    LoRa.sleep();  // Put the radio in sleep mode
    digitalWrite(3, LOW); // Sets the Latch pin 3 LOW For power cut off

    /* Set sleep mode to PWR_DOWN */
    // There are five different sleep modes in order of power saving:
    // SLEEP_MODE_IDLE - the lowest power saving mode
    // SLEEP_MODE_ADC
    // SLEEP_MODE_PWR_SAVE
    // SLEEP_MODE_STANDBY
    // SLEEP_MODE_PWR_DOWN - the highest power saving mode

    set_sleep_mode(SLEEP_MODE_PWR_DOWN);
    sleep_enable();
    sleep_mode();  // Now enter sleep mode.
}

```

Closed 2024-04-20.

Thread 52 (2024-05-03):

Waking up from deep sleep on MailboxGuard does not work

vladimir-aubrecht, 2024-05-03:
Hi,

I bought the mailbox guard, main features are working great, but struggling with waking up the MailboxGuard sensor. Could you please share details on how the device is getting waking up from deep sleep?

My current behaviour is that sensor reports new mail then it goes to deep sleep and does not wake up anymore until I take off battery and put it back (and even that does not work reliably).

PricelessToolkit, 2024-05-03:
HI Vladimir,

The mailbox sensor doesn't sleep at all; when triggered, it powers up the MCU and the LoRa radio. It can be activated by two mechanisms: the PIR sensor or the two contacts ("right side of the name") for the reed switch. The behavior you're describing is unusual.

1: If you don't touch the sensor and only wave your hand in front of the PIR sensor, does the LED turn on?
2: Or does the LED turn on, but you don't receive any signal?

vladimir-aubrecht, 2024-05-03:
Oh I see! I can move my hand or even move with it in any way and it will not turn on the LED 😕 Time to time blue LED is getting on after inserting battery, then it manages to send signal through LoRa and after that it turn off the LED and not reacting again ...

It's using default firmware which was there flashed - I did not touch it.

PricelessToolkit, 2024-05-03:
I think it was damaged during shipping, please contact me through Shop.  and add a link to this issue.

vladimir-aubrecht, 2024-05-03:
I will, thank you! 😊

Closed 2024-05-03.

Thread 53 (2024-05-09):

Question: possible to get PIR/Reed differentiated?

lexusburn, 2024-05-09:
I would like to ask, if it's possible to get the events from PIR/Reed differentiated?
As i can see, both sensors will wake up the sensor and then the sensor sends the lora message.
It would be great to get the possibility to differ between PIR and Reed for my use case.

PricelessToolkit, 2024-05-09:
Unfortunately, this is not possible with the current hardware version.

Closed 2024-05-09.

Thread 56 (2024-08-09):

magnet size for 3d printed case

tynick, 2024-08-09:
what magnets are you using for the following file?

`3D/STL/MailBoxGuard_Full_Size_Back_433_868_915.Magnet.stl`

PricelessToolkit, 2024-08-09:
10x5 but consider using "MailBoxGuard_Full_Size_Back_433_868_915_Magnetic_Open_12x2mm.STL" with 12x4-5mm magnet will stick out 2mm but it will be in direct contact with metal and will hold up much tight.

Closed 2024-08-09.

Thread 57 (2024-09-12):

Error when attempting to compile the mailbox code

mollgal, 2024-09-12:
Hi,
I'm getting an error while attempting to compile the mailbox code Mailbox_Guard_Sensor_Simple.ino, could you please help me figure it out?

Thanks

The error code I'm getting is:
```
Arduino: 1.8.19 (Linux), Board: "ATtiny3226/3216/1626/1616/1606/826/816/806/426/416/406, ATtiny1616, 5 MHz internal, 1.8V (5 MHz or less), Disabled/Disabled, EEPROM retained, Enabled (default timer), UPDI (no reset pin), 8ms, Master or Slave (saves flash and RAM), Default (doesn't print floats, 1.4k flash use), PB0-2, PA3-5, 1-series: PC0/1 (default), On all pins, with new implementation., Disabled (recommended), No delay before window "opens""

Warning: platform.txt from core 'megaTinyCore' contains deprecated compiler.path={runtime.tools.avr-gcc.path}/bin/, automatically converted to compiler.path=/usr/bin/. Consider upgrading this core.
In file included from /home/user/.arduino15/packages/megaTinyCore/hardware/megaavr/2.6.9/cores/megatinycore/Arduino.h:28:0,
                 from sketch/Mailbox_Guard_Sensor_Simple.ino.cpp:1:
/home/user/.arduino15/packages/megaTinyCore/hardware/megaavr/2.6.9/cores/megatinycore/core_devices.h:293:4: error: #error "No AC? No supported parts exist without one, something is wrong"
   #error "No AC? No supported parts exist without one, something is wrong"
    ^
/home/user/.arduino15/packages/megaTinyCore/hardware/megaavr/2.6.9/cores/megatinycore/core_devices.h:302:4: error: #error "No ADC? No supported parts exist without one, something is wrong"
   #error "No ADC? No supported parts exist without one, something is wrong"
    ^
/home/user/.arduino15/packages/megaTinyCore/hardware/megaavr/2.6.9/cores/megatinycore/core_devices.h:351:4: error: #error "No EVSYS detected? All supported parts have one, something is wrong"
   #error "No EVSYS detected? All supported parts have one, something is wrong"
    ^
In file included from /home/user/.arduino15/packages/megaTinyCore/hardware/megaavr/2.6.9/cores/megatinycore/Arduino.h:28:0,
                 from sketch/Mailbox_Guard_Sensor_Simple.ino.cpp:1:
/home/user/.arduino15/packages/megaTinyCore/hardware/megaavr/2.6.9/cores/megatinycore/core_devices.h:437:4: error: #error "No TCBs? No supported parts exist without one, something is wrong"
   #error "No TCBs? No supported parts exist without one, something is wrong"
    ^
/home/user/.arduino15/packages/megaTinyCore/hardware/megaavr/2.6.9/cores/megatinycore/core_devices.h:464:4: error: #error "No TWI? No supported parts exist without one, something is wrong"
   #error "No TWI? No supported parts exist without one, something is wrong"
    ^
/home/user/.arduino15/packages/megaTinyCore/hardware/megaavr/2.6.9/cores/megatinycore/core_devices.h:472:4: error: #error "No SPI? No supported parts exist without one, something is wrong"
   #error "No SPI? No supported parts exist without one, something is wrong"
    ^
/home/user/.arduino15/packages/megaTinyCore/hardware/megaavr/2.6.9/cores/megatinycore/core_devices.h:493:4: error: #error "No USARTs? No supported parts exist without one, something is wrong"
   #error "No USARTs? No supported parts exist without one, something is wrong"
    ^
In file included from /home/user/.arduino15/packages/megaTinyCore/hardware/megaavr/2.6.9/variants/txy6/pins_arduino.h:27:0,
                 from /home/user/.arduino15/packages/megaTinyCore/hardware/megaavr/2.6.9/cores/megatinycore/Arduino.h:708,
                 from sketch/Mailbox_Guard_Sensor_Simple.ino.cpp:1:
/home/user/.arduino15/packages/megaTinyCore/hardware/megaavr/2.6.9/cores/megatinycore/timers.h:149:6: error: #error "TCD0, selected for millis, does not exist on this part"
     #error "TCD0, selected for millis, does not exist on this part"
      ^
In file included from /home/user/.arduino15/packages/megaTinyCore/hardware/megaavr/2.6.9/cores/megatinycore/HardwareSerial.h:37:0,
                 from /home/user/.arduino15/packages/megaTinyCore/hardware/megaavr/2.6.9/cores/megatinycore/UART.h:5,
                 from /home/user/.arduino15/packages/megaTinyCore/hardware/megaavr/2.6.9/cores/megatinycore/Arduino.h:838,
                 from sketch/Mailbox_Guard_Sensor_Simple.ino.cpp:1:
/home/user/.arduino15/packages/megaTinyCore/hardware/megaavr/2.6.9/cores/megatinycore/UART_check_pins.h:35:4: error: #error "No USARTs present. All supported parts have at least 1 - something is wrong!"
   #error "No USARTs present. All supported parts have at least 1 - something is wrong!"
    ^
exit status 1
Error compiling for board ATtiny3226/3216/1626/1616/1606/826/816/806/426/416/406.

This report would have more information with
"Show verbose output during compilation"
option enabled in File -> Preferences.
```

PricelessToolkit, 2024-09-13:
Hi, Please can you check with the latest version of Arduino IDE? I remember someone had exactly the same problem on Linux.

mollgal, 2024-09-13:
I downloaded the latest version (instead of the one from the package manger) and there were no errors in the compilation.

Thanks a lot!

Closed 2024-09-13.

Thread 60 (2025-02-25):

Compilation error: 'WiFi' was not declared in this scope

leafkicker, 2025-02-25:
When verifying the LoRa_Gateway_HARestAPI.ino code in Arduino I always receive the following error:

`C:\temp\MailBoxGuard-main\Code\Arduino\LoRa_Gateway\LoRa_Gateway_HARestAPI\LoRa_Gateway_HARestAPI.ino: In function 'void setup_wifi()':
C:\temp\MailBoxGuard-main\Code\Arduino\LoRa_Gateway\LoRa_Gateway_HARestAPI\LoRa_Gateway_HARestAPI.ino:42:3: error: 'WiFi' was not declared in this scope
   42 |   WiFi.begin(ssid, password);
      |   ^~~~
C:\temp\MailBoxGuard-main\Code\Arduino\LoRa_Gateway\LoRa_Gateway_HARestAPI\LoRa_Gateway_HARestAPI.ino:44:27: error: 'WL_CONNECTED' was not declared in this scope
   44 |   while (WiFi.status() != WL_CONNECTED) {
      |                           ^~~~~~~~~~~~
Multiple libraries were found for "SSD1306Wire.h"
  Used: C:\Users\Ryan\Documents\Arduino\libraries\ESP8266_and_ESP32_OLED_driver_for_SSD1306_displays
  Not used: C:\Users\Ryan\Documents\Arduino\libraries\SSD1306
exit status 1

Compilation error: 'WiFi' was not declared in this scope`

I have spent hours trying to find this problem, testing with different computers and versions but I am unable to get this to work.

PricelessToolkit, 2025-02-25:
Fixed i added "#include <WiFi.h>" Can i ask why you choiced "LoRa_Gateway_HARestAPI.ino" frimvare ? with that firmware gateway is not universal. consider using "MQTT_JSON"  so you can add other DIY devices too, for more info check capibridge repo

PricelessToolkit, 2025-02-26:
If everything worked, please let me know so I can close this issue.

leafkicker, 2025-02-27:
thankyou it works!

Closed 2025-02-27.

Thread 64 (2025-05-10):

Disabling the LED and PIR

IDmedia, 2025-05-10:
I just received my mailbox sensor and intend to only use a reed switch with cables. While it's quite easy to see which holes you use for mounting the reed switch, I'm not quite sure how to understand the part about disabling the LED and PIR sensor. In the video you mentioned to "cut through the middle of the jumper pads". I guess that's best done with an x-acto knife? I found it strange that you would have to separate them by cutting instead of rather specifically enabling them by soldering the pads together. Wouldn't that have been much easier?

PricelessToolkit, 2025-05-10:
Yep, just do a couple of passes with an X-Acto knife.

For 99% of people, it's much easier to cut, and every home has a knife. If the LED or PIR were disabled by default, most users wouldn't know if the sensor is working out of the box. This way, it's active by default, and only those who want to disable them (like in your reed switch-only setup) need to make a simple modification.

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

IDmedia, 2025-05-10:
Thanks for your quick answer :)
What did you mean by the two pads your marked?

So as far as I understand, for my purpose of only Reed-switch I want to cut at least between the PIR pads and probably also the LED in order to save power(?). So if I for one reason or another would like to revert I'll just solder them back together. As for the Reed switch it seems that it should be soldered on the two outer holes right? Just got a bit confused what you meant by the picture.

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

PricelessToolkit, 2025-05-10:
1. Two outer holes or two right holes that I marked.
2. To enable, solder them back!

You can keep LED enabled, it will not use much power.

Closed 2025-05-10.

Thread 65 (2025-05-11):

Keep GATEWAY_KEY short

IDmedia, 2025-05-11:
Just out of curiosity, is there a technical reason why it says to keep GATEWAY_KEY short?

`#define GATEWAY_KEY "xy" // Keep it short`

PricelessToolkit, 2025-05-11:
1. The speed of sending – A shorter key means less data to transmit.
2. It's not for encryption – The key is just a simple identifier so the gateway can recognize messages meant for it.

Closed 2025-05-11.

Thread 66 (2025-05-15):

Powering the device without a battery

IDmedia, 2025-05-15:
I’m experiencing a strange issue with my setup. I successfully flashed the Lilygo gateway (`LoRa_Gateway_MQTT_JSON.ino`) and the mailbox sensor without any problems. Since I didn’t have the battery yet, I decided to power the sensor via USB temporarily for testing. Everything seemed to work perfectly: I could test it, create automations in Home Assistant, and confirm that the reed switch properly updated the state to "mail" and reset as expected. Satisfied with the results, I unplugged it, happy it was working as intended.

However, the next day, when I tried to assemble everything in preparation for the battery, the sensor stopped working when powered through the USB port. All I get now is a red LED and no state changes. When I connect the PCB clip and power it via the programmer board, the blue LED turns on and stays lit. In this state, it updates the sensor state to "mail" upon boot (which it shouldn't?), but the reed switch and motion sensor no longer trigger.

Did I damage the sensor by powering it via USB without a battery connected, or could I be missing something else? It’s odd because the sensor is still able to transmit data, and the gateway receives it, but the expected functionality isn’t working anymore.

PricelessToolkit, 2025-05-15:
1. Don't power it through USB; it is for charging only. When powered through the programming port, it will not work correctly. Power it with max 4.2 and use battery terminals.
2. It will not trigger again if you set the state from HA. You need to set the state in the MQTT topic!
3. I don't think you damaged it. Wait until you get the battery, with the power supply, the sensor logic is broken.

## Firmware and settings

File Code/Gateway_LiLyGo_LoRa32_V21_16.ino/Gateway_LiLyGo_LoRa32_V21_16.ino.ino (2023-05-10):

#include <SPI.h>
#include <LoRa.h>
#include "SSD1306Wire.h" 



#define OLED_RST  -1
#define LORA_MOSI 27
#define LORA_MISO 19
#define LORA_CLK  5
#define LORA_NSS  18
#define LORA_RST  23
#define LORA_DIO0 26
#define SDCARD_MOSI 15
#define SDCARD_MISO 2
#define SDCARD_SCLK 14
#define SDCARD_CS   13
#define BAND_PIN    4
#define LED_PIN    25

////////////////////////////////
#define SignalBandwidth 125E3
#define SpreadingFactor 12
#define CodingRate 8
#define SyncWord 0xF3
#define PreambleLength 8
#define TxPower 20
float BAND = 868E6;
////////////////////////////////


/////////////////////////////////
String NewMailCode = "0xA2B2";
String LowBatteryCode = "0xLBAT";
/////////////////////////////////

String recv;
int BAND_MODE = 0;
int ledState = LOW;  // ledState used to set the LED
int NewMailDetected = 0;
const long interval = 1000;  // interval at which to blink (milliseconds)
unsigned long previousMillis = 0;  // will store last time LED was updated



String Band915 = ("915000000.00," + String(SignalBandwidth) + "," + String(SpreadingFactor) + "," + String(CodingRate) + "," + String(SyncWord) + "," + String(PreambleLength) + "," + String(TxPower));
String Band868 = ("868000000.00," + String(SignalBandwidth) + "," + String(SpreadingFactor) + "," + String(CodingRate) + "," + String(SyncWord) + "," + String(PreambleLength) + "," + String(TxPower));

SSD1306Wire display(0x3C, 21, 22);

#define Bitmap_mail_logo_width 62
#define Bitmap_mail_logo_height 40
const unsigned char Bitmap_mail_logo [] PROGMEM = {
  0xf8, 0xff, 0xff, 0xff, 0xff, 0xff, 0xff, 0x07, 0xfc, 0xff, 0xff, 0xff, 0xff, 0xff, 0xff, 0x0f, 
  0xfe, 0xff, 0xff, 0xff, 0xff, 0xff, 0xff, 0x1f, 0xff, 0x00, 0x00, 0x00, 0x00, 0x00, 0xc0, 0x3f, 
  0xf7, 0x01, 0x00, 0x00, 0x00, 0x00, 0xe0, 0x3b, 0xe7, 0x03, 0x00, 0x00, 0x00, 0x00, 0xf0, 0x39, 
  0xc7, 0x07, 0x00, 0x00, 0x00, 0x00, 0xf8, 0x38, 0x87, 0x0f, 0x00, 0x00, 0x00, 0x00, 0x7c, 0x38, 
  0x07, 0x1e, 0x00, 0x00, 0x00, 0x00, 0x3e, 0x38, 0x07, 0x7c, 0x00, 0x00, 0x00, 0x00, 0x0f, 0x38, 
  0x07, 0xf8, 0x00, 0x00, 0x00, 0xc0, 0x07, 0x38, 0x07, 0xf0, 0x01, 0x00, 0x00, 0xe0, 0x03, 0x38, 
  0x07, 0xe0, 0x03, 0x00, 0x00, 0xf0, 0x01, 0x38, 0x07, 0xc0, 0x07, 0x00, 0x00, 0xf8, 0x00, 0x38, 
  0x07, 0x80, 0x0f, 0x00, 0x00, 0x7c, 0x00, 0x38, 0x07, 0x00, 0x3e, 0x00, 0x00, 0x3e, 0x00, 0x38, 
  0x07, 0x00, 0x7c, 0x00, 0x80, 0x0f, 0x00, 0x38, 0x07, 0x00, 0xf8, 0x00, 0xc0, 0x07, 0x00, 0x38, 
  0x07, 0x00, 0xf0, 0x01, 0xe0, 0x03, 0x00, 0x38, 0x07, 0x00, 0xe0, 0x03, 0xf0, 0x01, 0x00, 0x38, 
  0x07, 0x00, 0xc0, 0x07, 0xf8, 0x01, 0x00, 0x38, 0x07, 0x00, 0xf0, 0x0f, 0xfc, 0x03, 0x00, 0x38, 
  0x07, 0x00, 0xf8, 0x3e, 0xfe, 0x07, 0x00, 0x38, 0x07, 0x00, 0x7c, 0xfc, 0x8f, 0x0f, 0x00, 0x38, 
  0x07, 0x00, 0x3e, 0xf8, 0x07, 0x1f, 0x00, 0x38, 0x07, 0x00, 0x1f, 0xf0, 0x03, 0x3e, 0x00, 0x38, 
  0x07, 0x80, 0x0f, 0xe0, 0x01, 0xf8, 0x00, 0x38, 0x07, 0xe0, 0x03, 0xc0, 0x00, 0xf0, 0x01, 0x38, 
  0x07, 0xf0, 0x01, 0x00, 0x00, 0xe0, 0x03, 0x38, 0x07, 0xf8, 0x00, 0x00, 0x00, 0xc0, 0x07, 0x38, 
  0x07, 0x7c, 0x00, 0x00, 0x00, 0x80, 0x0f, 0x38, 0x07, 0x3e, 0x00, 0x00, 0x00, 0x00, 0x1f, 0x38, 
  0x07, 0x1f, 0x00, 0x00, 0x00, 0x00, 0x3c, 0x38, 0x87, 0x07, 0x00, 0x00, 0x00, 0x00, 0xf8, 0x38, 
  0xe7, 0x03, 0x00, 0x00, 0x00, 0x00, 0xf0, 0x39, 0xf7, 0x01, 0x00, 0x00, 0x00, 0x00, 0xe0, 0x3b, 
  0xff, 0x00, 0x00, 0x00, 0x00, 0x00, 0xc0, 0x3f, 0xfe, 0xff, 0xff, 0xff, 0xff, 0xff, 0xff, 0x1f, 
  0xfc, 0xff, 0xff, 0xff, 0xff, 0xff, 0xff, 0x1f, 0xf8, 0xff, 0xff, 0xff, 0xff, 0xff, 0xff, 0x07
};



#define Bitmap_battery_full_width 27
#define Bitmap_battery_full_height 15
const unsigned char Bitmap_battery_full [] PROGMEM = {


  0xff, 0xff, 0xff, 0x00, 0xff, 0xff, 0xff, 0x00, 0x03, 0x00, 0x80, 0x00, 0x33, 0xe6, 0x9c, 0x03, 
  0x7b, 0xe7, 0x9c, 0x07, 0x7b, 0xe7, 0x9c, 0x07, 0x7b, 0xe7, 0x9c, 0x07, 0x7b, 0xe7, 0x9c, 0x07, 
  0x7b, 0xe7, 0x9c, 0x07, 0x7b, 0xe7, 0x9c, 0x07, 0x7b, 0xe7, 0x9c, 0x07, 0x33, 0xe6, 0x9c, 0x03, 
  0x03, 0x00, 0x80, 0x00, 0xff, 0xff, 0xff, 0x00, 0xff, 0xff, 0xff, 0x00
  
};


#define Bitmap_battery_transparent_width 27
#define Bitmap_battery_transparent_height 15
const unsigned char Bitmap_battery_transparent [] PROGMEM = {


  0xff, 0xff, 0xff, 0x01, 0xff, 0xff, 0xff, 0x01, 0xe7, 0xff, 0xdf, 0x01, 0x3f, 0x00, 0xc0, 0x07, 
  0x3f, 0x00, 0xc0, 0x07, 0x3f, 0x00, 0xc0, 0x07, 0x3f, 0x00, 0xc0, 0x07, 0x3f, 0x00, 0xc0, 0x07, 
  0x3f, 0x00, 0xc0, 0x07, 0x3f, 0x00, 0xc0, 0x07, 0x3f, 0x00, 0xc0, 0x07, 0x3f, 0x00, 0xc0, 0x07, 
  0x07, 0x00, 0xc0, 0x01, 0xff, 0xff, 0xff, 0x01, 0xff, 0xff, 0xff, 0x01
  
};



#define Bitmap_battery_empty_width 27
#define Bitmap_battery_empty_height 15
const unsigned char Bitmap_battery_empty [] PROGMEM = {


  0xfe, 0xff, 0xff, 0x00, 0xff, 0xff, 0xff, 0x00, 0x03, 0x00, 0x80, 0x00, 0x03, 0x00, 0x80, 0x01, 
  0x13, 0x00, 0x80, 0x07, 0x13, 0x00, 0x80, 0x07, 0x13, 0x00, 0x80, 0x07, 0x13, 0x00, 0x80, 0x07, 
  0x13, 0x00, 0x80, 0x07, 0x13, 0x00, 0x80, 0x07, 0x13, 0x00, 0x80, 0x07, 0x13, 0x00, 0x80, 0x03, 
  0x03, 0x00, 0x80, 0x00, 0xff, 0xff, 0xff, 0x00, 0xfe, 0xff, 0xff, 0x00
  
};



void setup() {
  Serial.begin(9600);
  while (!Serial);
  
  if (OLED_RST > 0) {
      pinMode(OLED_RST, OUTPUT);
      digitalWrite(OLED_RST, HIGH);
      delay(100);
      digitalWrite(OLED_RST, LOW);
      delay(100);
      digitalWrite(OLED_RST, HIGH);
  }
  display.init();
  
  pinMode(BAND_PIN, INPUT);
  pinMode(LED_PIN, OUTPUT);
  digitalWrite(LED_PIN, LOW);
  BAND_MODE = digitalRead(BAND_PIN);
  if (BAND_MODE == HIGH){
      BAND = 915E6;
      Serial.println(Band915);
      display.flipScreenVertically();
      display.setFont(ArialMT_Plain_10);
      display.setTextAlignment(TEXT_ALIGN_CENTER);
      display.drawString(64, 5, "PricelessToolkit");
      display.setFont(ArialMT_Plain_16);
      display.setTextAlignment(TEXT_ALIGN_CENTER);
      display.drawString(64, 20, "MailBox Guard");
      display.drawString(64, 38, "RX 915MHz");
      display.display();
      delay(2000);
      display.clear();
      display.display();
      
  }
  else
     {
      Serial.println(Band868);
      display.flipScreenVertically();
      display.setFont(ArialMT_Plain_10);
      display.setTextAlignment(TEXT_ALIGN_CENTER);
      display.drawString(64, 5, "PricelessToolkit");
      display.setFont(ArialMT_Plain_16);
      display.setTextAlignment(TEXT_ALIGN_CENTER);
      display.drawString(64, 20, "MailBox Guard");
      display.drawString(64, 38, "RX 868MHz");
      display.display();
      delay(2000);
      display.clear();
      display.display();
    
     }

  




  SPI.begin(LORA_CLK, LORA_MISO, LORA_MOSI, LORA_NSS);
  LoRa.setPins(LORA_NSS, LORA_RST, LORA_DIO0);
  //Serial.println("Starting LoRa on " + String(BAND)+ " MHz");
  if (!LoRa.begin(BAND)) {
      Serial.println("Starting LoRa failed!");
      while (1);
  }
  
  LoRa.setSignalBandwidth(SignalBandwidth);         // signal bandwidth in Hz, defaults to 125E3
  LoRa.setSpreadingFactor(SpreadingFactor);                 // ranges from 6-12,default 7 see API docs
  LoRa.setCodingRate4(CodingRate);        // Supported values are between 5 and 8, these correspond to coding rates of 4/5 and 4/8. The coding rate numerator is fixed at 4.
  LoRa.setSyncWord(SyncWord);                     // byte value to use as the sync word, defaults to 0x12
  LoRa.setPreambleLength(PreambleLength);       //Supported values are between 6 and 65535.
  LoRa.disableCrc();                          // Enable or disable CRC usage, by default a CRC is not used LoRa.disableCrc();
  LoRa.setTxPower(TxPower);                // TX power in dB, defaults to 17, Supported values are 2 to 20
  
}


int count = 0;

void NewMailLed()
{

   if (NewMailDetected == 1){
    unsigned long currentMillis = millis();
    if (currentMillis - previousMillis >= interval) {
    // save the last time you blinked the LED
    previousMillis = currentMillis;

    // if the LED is off turn it on and vice-versa:
    if (ledState == LOW) {
      ledState = HIGH;
    } else {
      ledState = LOW;
    }

    // set the LED with the ledState of the variable:
    digitalWrite(LED_PIN, ledState);
  }
 }
  
}



void loop()
{
  
    NewMailLed();

    if (LoRa.parsePacket()) {
        String recv = "";
        while (LoRa.available()) {
            recv += (char)LoRa.read();
        }
        
        count++;
        Serial.println(recv);

////////////////////////////////////PROD///////////////////////////////////////////////

        if (recv == NewMailCode){
            NewMailDetected = 1;
            display.clear();
            display.drawXbm(63, 3, Bitmap_mail_logo_width, Bitmap_mail_logo_height, Bitmap_mail_logo);
            display.drawXbm(97, 48, Bitmap_battery_full_width, Bitmap_battery_full_height, Bitmap_battery_full);
            display.setTextAlignment(TEXT_ALIGN_LEFT);
            display.setFont(ArialMT_Plain_16);
            display.drawString(3, 3, "NEW");
            display.drawString(18, 20, "MAIL");
            int NewMailCount = count / 2;
            display.drawString(89, 6, String(NewMailCount));
            //display.setTextAlignment(TEXT_ALIGN_LEFT);
            display.setFont(ArialMT_Plain_16);
            String rss = "RSSI: " + String(LoRa.packetRssi());
            display.drawString(5, 47, String(rss));
            display.display();
            
         }
        
         if (recv == LowBatteryCode){
              display.clear();
              NewMailDetected = 1;
              display.drawXbm(63, 3, Bitmap_mail_logo_width, Bitmap_mail_logo_height, Bitmap_mail_logo);
              display.drawXbm(97, 48, Bitmap_battery_full_width, Bitmap_battery_full_height, Bitmap_battery_empty);
              display.setTextAlignment(TEXT_ALIGN_LEFT);
              display.setFont(ArialMT_Plain_16);
              display.drawString(3, 3, "NEW");
              display.drawString(18, 20, "MAIL");
              int NewMailCount = count / 2;
              display.drawString(89, 6, String(NewMailCount));
              //display.setTextAlignment(TEXT_ALIGN_LEFT);
              display.setFont(ArialMT_Plain_16);
              String rss = "RSSI: " + String(LoRa.packetRssi());
              display.drawString(5, 47, String(rss));
              display.display();
         }
  

///////////////////////////////////////////////////////////////////////////////////////////

////////////////////////////////////TEST///////////////////////////////////////////////
/*
        digitalWrite(LED_PIN, HIGH);
        delay(5);
        digitalWrite(LED_PIN, LOW);

        String info = "CODE: " + String(recv);
        String rss = "RSSI: " + String(LoRa.packetRssi());
        String msg = "MSG: " + String(count);
        //Serial.println(rss);
        display.clear();
        display.setTextAlignment(TEXT_ALIGN_LEFT);
        display.setFont(ArialMT_Plain_10);
        display.drawString(5, 5, String(info));
        display.drawString(5, 20, String(rss));
        display.setFont(ArialMT_Plain_16);
        display.drawString(5, 35, String(msg));
        display.display();

        if (String(recv)== "0xLBAT"){
          display.setFont(ArialMT_Plain_16);
          display.drawString(90, 35, "[LB]");
          display.display();
        }
*/
///////////////////////////////////////////////////////////////////////////////////////////


  } 

}

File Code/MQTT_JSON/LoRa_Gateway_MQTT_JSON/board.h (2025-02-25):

#include <Arduino.h>

//////////////// SELECT BOARD ///////////////////////

#define LORA_V1_0_OLED  0
#define LORA_V1_2_OLED  0
#define LORA_V1_3_OLED  0
#define LORA_V1_6_OLED  1
#define LORA_V2_0_OLED  0  // ON = 1 / OFF = 0

//////////////////////////////////////////////////////

#if LORA_V1_0_OLED
#include <Wire.h> 
#include "SSD1306Wire.h" 
#define OLED_CLASS_OBJ  SSD1306Wire
#define OLED_ADDRESS    0x3C
#define OLED_SDA    4
#define OLED_SCL    15
#define OLED_RST    16

#define LED_PIN    25

#define CONFIG_MOSI 27
#define CONFIG_MISO 19
#define CONFIG_CLK  5
#define CONFIG_NSS  18
#define CONFIG_RST  14
#define CONFIG_DIO0 26
// !    There are two versions of TTGO LoRa V1.0, 
// !    the 868 version uses the 3D WiFi antenna, and the 433 version uses the PCB antenna. 
// !    You need to change the frequency according to the board.


#elif LORA_V1_3_OLED
#include <Wire.h> 
#include "SSD1306Wire.h" 
#define OLED_CLASS_OBJ  SSD1306Wire
#define OLED_ADDRESS    0x3C
#define OLED_SDA    4
#define OLED_SCL    15
#define OLED_RST    -1

#define LED_PIN    25

#define CONFIG_MOSI 27
#define CONFIG_MISO 19
#define CONFIG_CLK  5
#define CONFIG_NSS  18
#define CONFIG_RST  23
#define CONFIG_DIO0 26


#define SDCARD_MOSI -1
#define SDCARD_MISO -1
#define SDCARD_SCLK -1
#define SDCARD_CS   -1

#elif LORA_V1_2_OLED
//Lora V1.2 ds3231
#include <Wire.h> 
#include "SSD1306Wire.h" 
#define OLED_CLASS_OBJ  SSD1306Wire
#define OLED_ADDRESS    0x3C
#define OLED_SDA    21
#define OLED_SCL    22
#define OLED_RST    -1

#define LED_PIN    25

#define CONFIG_MOSI 27
#define CONFIG_MISO 19
#define CONFIG_CLK  5
#define CONFIG_NSS  18
#define CONFIG_RST  23
#define CONFIG_DIO0 26

#define SDCARD_MOSI -1
#define SDCARD_MISO -1
#define SDCARD_SCLK -1
#define SDCARD_CS   -1

#define ENABLE_DS3231

#elif LORA_V1_6_OLED
#include <Wire.h> 
#include "SSD1306Wire.h" 
#define OLED_CLASS_OBJ  SSD1306Wire
#define OLED_ADDRESS    0x3C
#define OLED_SDA    21
#define OLED_SCL    22
#define OLED_RST    -1

#define LED_PIN    25

#define CONFIG_MOSI 27
#define CONFIG_MISO 19
#define CONFIG_CLK  5
#define CONFIG_NSS  18
#define CONFIG_RST  23
#define CONFIG_DIO0 26

#define SDCARD_MOSI 15
#define SDCARD_MISO 2
#define SDCARD_SCLK 14
#define SDCARD_CS   13

#elif LORA_V2_0_OLED
#include <Wire.h> 
#include "SSD1306Wire.h" 
#define OLED_CLASS_OBJ  SSD1306Wire
#define OLED_ADDRESS    0x3C
#define OLED_SDA    21
#define OLED_SCL    22
#define OLED_RST    -1

#define LED_PIN    25

#define CONFIG_MOSI 27
#define CONFIG_MISO 19
#define CONFIG_CLK  5
#define CONFIG_NSS  18
#define CONFIG_RST  23
#define CONFIG_DIO0 26

#define SDCARD_MOSI 15
#define SDCARD_MISO 2
#define SDCARD_SCLK 14
#define SDCARD_CS   13

#else
#error "please select board"
#endif

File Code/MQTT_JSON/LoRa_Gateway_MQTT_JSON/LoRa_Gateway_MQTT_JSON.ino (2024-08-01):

#include <Arduino.h>
#include "board.h"
#include "config.h"
#include <SPI.h>
#include <LoRa.h>
#include <WiFi.h>
#include <PubSubClient.h>
#include <ArduinoJson.h>
#include "SSD1306Wire.h"

SSD1306Wire display(OLED_ADDRESS, OLED_SDA, OLED_SCL);

#define BAUD 115200

#define MQTT_RETAIN true
#define BINARY_SENSOR_TOPIC "homeassistant/binary_sensor/"
#define SENSOR_TOPIC "homeassistant/sensor/"
#define LoRaGateway_RSSI_TOPIC "homeassistant/sensor/LoRaGateway/rssi"

unsigned long LedStartTime = 0;
unsigned long diagTimer = 60000;
unsigned long lastDiagTimer = 0;
unsigned long currentDiagMillis;

struct json_msg {
  String k;
  String id;
  int16_t r;
  int16_t b;
  int16_t v;
  float pw;
  int16_t l;
  String m;
  float w;
  String s;
  int16_t e;
  float t;
  float t2;
  int16_t hu;
  int16_t mo;
  String rw;
  String bt;
  float atm;
  float cd;
  String dr;
  String wd;
  String vb;
};

json_msg received_json_message;

WiFiClient espClient;
PubSubClient client(espClient);

void setup_wifi() {
  delay(10);
  Serial.println();
  Serial.print("Connecting to ");
  Serial.println(WIFI_SSID);

  WiFi.begin(WIFI_SSID, WIFI_PASSWORD);

  while (WiFi.status() != WL_CONNECTED) {
    delay(500);
    Serial.print(".");
  }

  Serial.println("");
  Serial.println("WiFi connected");
  Serial.println("IP address: ");
  Serial.println(WiFi.localIP());
}


void reconnect() {
  while (!client.connected()) {
    Serial.print("Attempting MQTT connection...");
    // Buffer needs to be increased to accomodate the config payloads
    if (client.setBufferSize(1024)) {
      Serial.println("Buffer Size increased to 1024 byte");
    } else {
      Serial.println("Failed to allocate larger buffer");
    }

    String client_id = "LoRaGateway";

    if (client.connect(client_id.c_str(), MQTT_USERNAME, MQTT_PASSWORD)) {
      Serial.println("MQTT connected");

      Serial.println("Buffersize: " + client.getBufferSize());


        
    } else {
      Serial.print("MQTT failed, rc=");
      Serial.print(client.state());
      Serial.println(" try again in 1 seconds");
      delay(1000);
    }
  }
}



void setup() {
  Serial.begin(115200);

  display.init();

  display.flipScreenVertically();
  display.setFont(ArialMT_Plain_10);
  display.setTextAlignment(TEXT_ALIGN_CENTER);
  display.drawString(64, 5, "PricelessToolkit");
  display.setFont(ArialMT_Plain_16);
  display.setTextAlignment(TEXT_ALIGN_CENTER);
  display.drawString(64, 20, "LiLyGateway");
  display.drawString(64, 38, "RX " + String(BAND));
  display.display();
  delay(2000);
  display.clear();
  display.display();



  setup_wifi();
  client.setServer(MQTT_SERVER, MQTT_PORT);
  reconnect();
  
  pinMode(LED_PIN, OUTPUT);
  digitalWrite(LED_PIN, HIGH);   // HIGH = OFF

  SPI.begin(CONFIG_CLK, CONFIG_MISO, CONFIG_MOSI, CONFIG_NSS);
  LoRa.setPins(CONFIG_NSS, CONFIG_RST, CONFIG_DIO0);
  Serial.println("Starting LoRa on " + String(BAND) + " MHz");
  if (!LoRa.begin(BAND)) {
    Serial.println("Starting LoRa failed!");
    while (1) {}
  }

  LoRa.setSignalBandwidth(SIGNAL_BANDWITH);  // signal bandwidth in Hz, defaults to 125E3
  LoRa.setSpreadingFactor(SPREADING_FACTOR);  // ranges from 6-12,default 7 see API docs
  LoRa.setCodingRate4(CODING_RATE);  // Supported values are between 5 and 8, these correspond to coding rates of 4/5 and 4/8. The coding rate numerator is fixed at 4.
  LoRa.setSyncWord(SYNC_WORD);  // byte value to use as the sync word, defaults to 0x12
  LoRa.setPreambleLength(PREAMBLE_LENGTH);  // Supported values are between 6 and 65535.
  LoRa.disableCrc();  // Enable or disable CRC usage, by default a CRC is not used LoRa.disableCrc() / LoRa.enableCrc();;
  LoRa.setTxPower(TX_POWER);  // TX power in dB, defaults to 17, Supported values are 2 to 20

}



void publishIfKeyExists(const JsonDocument& doc, const char* key, const String& topicSuffix) {
  if (doc.containsKey(key)) {
    String topic = String(SENSOR_TOPIC) + String(received_json_message.id) + topicSuffix;
    String binTopic = String(BINARY_SENSOR_TOPIC) + String(received_json_message.id) + topicSuffix;
    String value;

    // Determine the type of the key value and convert to string appropriately
    if (doc[key].is<int>()) {
      // For integers
      value = String(doc[key].as<int>());
    } else if (doc[key].is<float>()) {
      // For floats
      value = String(doc[key].as<float>(), 2); // Assuming 2 decimal places for float
    } else if (doc[key].is<String>()) {
      // For strings
      value = doc[key].as<String>();
    } else {
      // If the type is not expected, you can log an error or handle accordingly
      Serial.println("Unsupported type for key: " + String(key));
      return;
    }


 ///////////////////////// auto-discovery ////////////////////////////////



    // auto-discovery for Battery
    if (doc.containsKey("b")) {
        

    client.publish(
        (String(SENSOR_TOPIC) + String(received_json_message.id).c_str() + "/batt/config").c_str(),
        (String("{"
        "\"name\":\"Battery\","
        "\"device_class\":\"battery\","
        "\"unit_of_measurement\":\"%\","
        "\"icon\":\"mdi:battery\","
        "\"entity_category\":\"diagnostic\","
        "\"state_topic\":\"") + String(SENSOR_TOPIC) + String(received_json_message.id).c_str() + "/batt" + "\","
        "\"unique_id\":\"" + String(received_json_message.id).c_str() + "_batt" +"\","
        "\"device\":{\"identifiers\":[\"" + String(received_json_message.id).c_str() + "\"],"
        "\"name\":\"" + String(received_json_message.id).c_str() +"\","
        "\"mdl\":\"" + String(received_json_message.id).c_str() +
        "\",\"mf\":\"PricelessToolkit\"}}").c_str(),
        MQTT_RETAIN);

      }

    // auto-discovery for RSSI
    if (doc.containsKey("r")) {


    client.publish(
      (String(SENSOR_TOPIC) + String(received_json_message.id).c_str() + "/rssi/config").c_str(),
      (String("{"
        "\"name\":\"RSSI\","
        "\"unit_of_measurement\":\"dBm\","
        "\"device_class\":\"signal_strength\","
        "\"icon\":\"mdi:signal\","
        "\"entity_category\":\"diagnostic\","
        "\"state_topic\":\"") + String(SENSOR_TOPIC) + String(received_json_message.id).c_str() +  "/rssi" +"\","
        "\"unique_id\":\"" + String(received_json_message.id).c_str() + "_rssi" +"\","
        "\"device\":{\"identifiers\":[\"" + String(received_json_message.id).c_str() + "\"],"
        "\"name\":\"" + String(received_json_message.id).c_str() + "\"}}").c_str(),
      MQTT_RETAIN);

      }

    
    // auto-discovery for Row data TEXT
    if (doc.containsKey("rw")) {
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

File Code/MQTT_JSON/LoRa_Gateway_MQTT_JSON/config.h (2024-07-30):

/////////////////////////// LoRa Gateway Key ///////////////////////////

#define GATEWAY_KEY "xy" // Keep it Tiny

///////////////////////////////////////////////////////////////////////////////

////////////////////////////// WIFI / MQTT ////////////////////////////////////

#define WIFI_SSID "xxxx"
#define WIFI_PASSWORD "xxxx"
#define MQTT_USERNAME "xxxx"
#define MQTT_PASSWORD "xxxx"
#define MQTT_SERVER "xxxx"
#define MQTT_PORT 1883

///////////////////////////////////////////////////////////////////////////////


////////////////////////////// LORA CONFIG ////////////////////////////////////

// For sending 6 bytes "6 characters" of data using different Spreading Factors (SF), the estimated time on air (ToA)
// for each SF is as follows:

// SF7: Approximately 0.027 seconds (27.494 milliseconds)
// SF8: Approximately 0.052 seconds (52.224 milliseconds)
// SF9: Approximately 0.100 seconds (100.147 milliseconds)
// SF10: Approximately 0.193 seconds (193.413 milliseconds)
// SF11: Approximately 0.385 seconds (385.297 milliseconds)
// SF12: Approximately 0.746 seconds (746.127 milliseconds)
// These calculations demonstrate how the time on air increases with higher Spreading Factors
// due to the decreased data rate, which is a trade-off for increased communication range and signal robustness.

#define SIGNAL_BANDWITH 125E3  // signal bandwidth in Hz, defaults to 125E3
#define SPREADING_FACTOR 8    // ranges from 6-12,default 7 see API docs
#define CODING_RATE 5          // Supported values are between 5 and 8, these correspond to coding rates of 4/5 and 4/8. The coding rate numerator is fixed at 4.
#define SYNC_WORD 0xF3         // byte value to use as the sync word, defaults to 0x12
#define PREAMBLE_LENGTH 6      // Supported values are between 6 and 65535.
#define TX_POWER 20            // TX power in dB, defaults to 17, Supported values are 2 to 20
#define BAND 868E6             // 433E6 / 868E6 / 915E6

///////////////////////////////////////////////////////////////////////////////

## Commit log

2023-05-10 3D files
    [Assem1.SLDASM, MailBoxGuard_Full_Size_Back_868_915.SLDPRT, MailBoxGuard_Full_Size_Back_868_915.STL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]
2023-06-02 Easy Board Selection
2023-06-03 arduino board config
2023-06-04 board definition
2023-08-12 Wall Support
    [Wall_Support_BT14500.SLDPRT, Wall_Support_BT14500.STL]
2023-08-15 Gerber and Schematic
    [Assem1.SLDASM, MailBoxGuard_Full_Size_Back_868_915.SLDPRT, MailBoxGuard_Full_Size_Front_868_915.SLDPRT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]
2023-08-17 STL
    Increased the space for 433MHa antenna . And slightly increased the space for the PCB.
    [MailBoxGuard_Full_Size_Back_433_868_915.SLDPRT, MailBoxGuard_Full_Size_Back_433_868_915.STL, MailBoxGuard_Full_Size_Back_868_915.SLDPRT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]
2023-08-21 added Mfr parts
    [MailBox_Guard_Boom.csv]
2023-09-05 Fixed MQTT Autodiscovery for Homeassistant and added battery percentage + warning, manufacturer and model
2023-09-05 Fixed a battery percentage bug. Added stability measures to gateway to catch transmissions w/o battery percentage payloads
2023-09-07 Add battery level to HARestAPI example
2023-09-07 LCSC Part numbers
    [MailBox_Guard_Boom.csv]
2023-09-08 Added 3D STEP Files
    [MailBoxGuard_Full_Size_Back_433_868_915.STEP, MailBoxGuard_Full_Size_Front_433.STEP, MailBoxGuard_Full_Size_Front_868_915.STEP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]
2023-09-09 Cap Voltage
    [MailBox_Guard_Boom.csv]
2023-09-14 Reed switch link
2023-09-18 Update README.md
    Separate charger link
2023-09-21 Create automation_MQTT_Auto_Discovery.yaml
    Automation to deal with reset of state for auto discovered sensor
2023-09-28 add unit of measurement to rssi and battery
2023-10-16 Constrain battery percentage between 0 and 100
2024-01-20 Reworking Communication and Code
    LoRa Gateway
    - add secrets.h to store wifi and mqtt credentials
    - set lora setting to defaults (see Mailbox Sensor)
    - moved most const something variables to #define
    - created a struct to store lora message contents
    - parse JSON string coming via lora (see Mailbox Sensor)
    - removed "magic numbers" from code where applicable and made them
    configurable
    - removed battery percentage mqtt topic (does not make sense)
    - removed battery low alert (also does not make sense)
    - added battery voltage topic
    - ran cpplint to fix appearance (except some line length issues) and
    fixed some naming convention issues
    Mailbox Sensor
    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
2024-01-21 Changed TX power and spreading factor
    TX Power Set to 20 SF to 12
2024-01-31 Fix battery icon for Home Assistant
2024-03-01 3D Magnetic back Cover
    RIMSKO provided new magnetic back cover.
    [MailBoxGuard_Full_Size_Back_433_868_915.Magnet.step, MailBoxGuard_Full_Size_Back_433_868_915.Magnet.stl, Restriktor.step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]
2024-06-15 Battery in percent "CapiBridge"
